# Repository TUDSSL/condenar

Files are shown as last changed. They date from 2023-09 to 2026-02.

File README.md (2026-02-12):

# TURNER Games Console

This is the official public repository for the TURNER battery-free gaming console.

<p align="center">
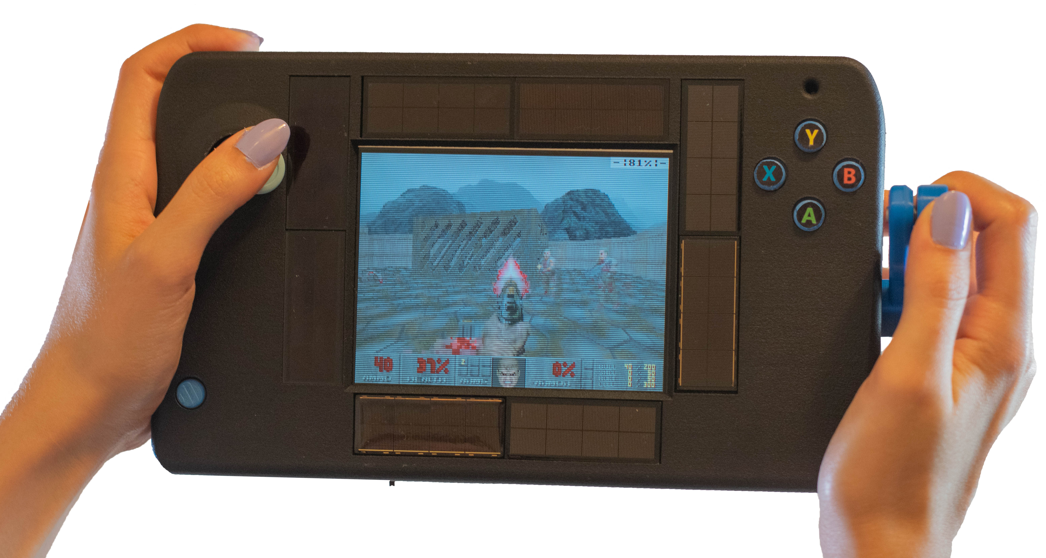
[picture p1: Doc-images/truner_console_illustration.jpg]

</p>

<p align="center">
  <sub><strong>Figure 1.</strong> The battery-free TURNER console in action. Turning the crank enables weapon firing in DOOM while simultaneously generating energy to charge TURNER’s energy-storage capacitor. The capacitor’s charging state is shown by a small indicator at the top-right of the LCD panel. TURNER integrates solar energy harvesting, follows the form factor of a modern handheld game console, and features the standard “ABXY” button configuration. The current implementation weighs 509 g; the casing measures 24 cm × 14 cm × 3 cm, and the crank measures 2 cm × 6.5 cm × 2 cm.</sub>
</p>

## System Design Rationale

Battery-free computer gaming offers a vision of sustainable interaction in which games run on hardware that does not require a battery, yet this approach introduces uncertainty due to frequent power failures. Rather than viewing these failures as limitations, this work examines how integrating energy harvesting with application design can encourage users to reimagine and work with such failures, thus shaping behaviour and supporting device use. We present TURNER, a state-of-the-art modular battery-free games console powered by a hand crank and solar cells, created as a research probe to study how energy harvesting mediates the relationship between power and interaction. 

In a subsequent mixed-methods study (N = 60), we explored the influence of energy harvesting on gameplay. Findings show significant variations in harvesting strategies, with interviews surfacing strategies for creating applications that respond to and build on the patterns of system power failure, the ergonomics of energy harvesting, and the value of embedding energy generation into play. Our work offers insights for interactive, sustainable battery-free computers.

## Repository Structure

- [/Hardware](https://github.com/tudssl/condenar/tree/master/Hardware): This folder contains the source files for the hardware used in this project.
- [/Software](https://github.com/tudssl/condenar/tree/master/Software): The folder contains the software used in the TURNER console (including console firmware, apps, and logging software).
- [/Data](https://github.com/tudssl/condenar/tree/master/Data): This folder contains the data and data analysis scripts used in the TURNER user study.
- [/Doc-images](https://github.com/TUDSSL/condenar/tree/master/Doc-images): This folder contains images of the TURNER console. 

## TURNER System Description

<p align="center">
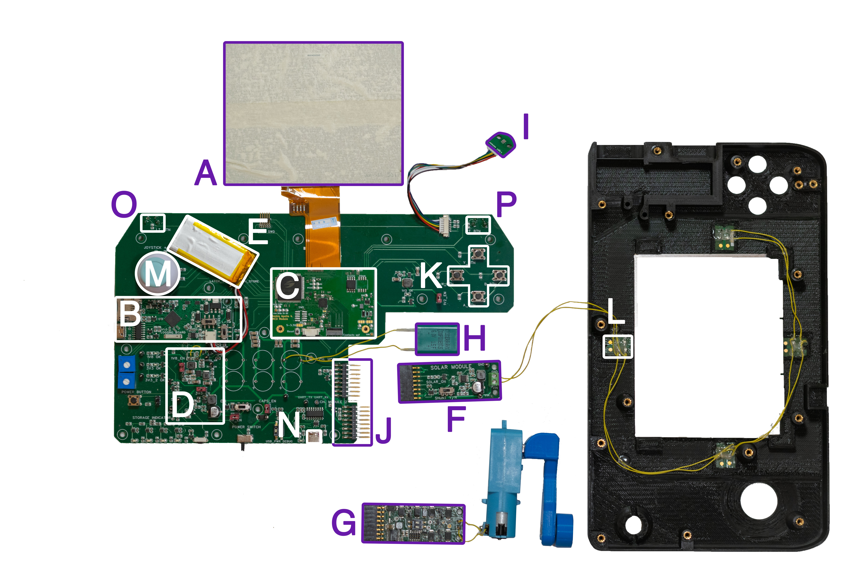
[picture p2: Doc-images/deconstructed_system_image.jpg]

</p>

<p align="center">
  <sub><strong>Figure 2.</strong> TURNER system implementation: (A) back of the COM50H5M81XLC transflective LCD screen; (B) logging module using an Espressif Systems ESP32 PICO Series microcontroller; (C) Central Processing Unit (CPU) module using an Ambiq Apollo4 MCU; (D) power management; (E) logging module battery; (F) solar module implemented around the Analog Devices LTC3129 Maximum Power Point Tracking (MPPT) buck-boost energy harvester; (G) crank module; (H) 6V 1.5F Kyocera AVX-SCM supercapacitor (SCMR22H155PSBB0); (I) ambient light sensor; (J) energy module connection points; (K) “ABXY” buttons; (L) solar panel connection on the front of the system casing. Eight ExCellLight EXL10-4V170 high-performance solar cells (50 mm × 20 mm each) are deployed; (M) joystick; (N) Universal Serial Bus (USB) port; (O) left trigger button; (P) right trigger button. The battery is used <em>only</em> to power the logging module and during the battery-powered console configuration experimental condition.</sub>
</p>

## TURNER User Study

The user study of TURNER employed a mixed-methods approach, combining console log data, questionnaire responses, and post-study interviews. The study was [pre-registed at Open Science Framework (OSF)](http://osf.io/7fp2w). 

### Quantitative Analysis

A range of statistical tests were used to assess the significance of effects in our log and questionnaire data. Parametric tests were applied when assumptions of normality, from Shapiro-Wilk, and homoscedasticity, from Levene's tests, were met. To analyse differences among more than two groups, we used Analysis of Variance (ANOVA) for between-subjects designs and repeated-measures ANOVA for within-subjects designs when parametric assumptions held, and Kruskal–Wallis or Friedman tests when non-parametric, respectively. Significant results were followed by post-hoc pairwise comparisons using Tukey’s HSD (parametric) or Dunn’s test with Bonferroni correction (non-parametric). For comparisons between two groups, we used independent samples t-tests or Mann-Whitney U tests, as appropriate. 

### Qualitative Analysis

We analysed post-study interviews using inductive thematic analysis, following the six-phase guidance proposed by [Braun and Clarke](https://www.tandfonline.com/doi/abs/10.1191/1478088706qp063oa). Coding was inductive, with initial descriptive and in vivo codes generated through repeated engagement with participants’ responses. Codes were iteratively refined and grouped into broader patterns through multiple rounds of analysis. 

## How to Cite This Work

The results of this project will be published in a peer-reviewed academic publication (from which all technical figures and most of the text in this file originate). Details of the publication are as follows.

* **Authors and the project team:** [James Scott Broadhead](https://scholar.google.com/citations?user=sMDFHlMAAAAJ), [Jasper de Winkel](https://jasperdewinkel.com), [Alejandro Cabrerizo Martinez de La Puente](https://www.linkedin.com/in/alejandro-cabrerizo-03780b136), [Himanshu Verma](https://vermahimanshu.com), [Przemysław Pawełczak](http://www.pawelczak.net)
* **Publication title:** _Connecting Power and Play: Investigating Interactive Energy Harvesting in Battery-Free Gaming_

<!--
* **Pulication venue:** [Proceedings of the 2026 CHI Conference on Human Factors in Computing Systems (CHI '26), April 13-17, 2026, Barcelona, Spain](https://dl.acm.org/)
* **Link to publication:** https://doi.org/10.1145/3772318.3790831 (Open Access)
* **Link to ACM CHI 2026 conference presentation video:** https://www.youtube.com/watch?
-->

<!--
To cite this publication please use the following BiBTeX entry.

```
@article{broadhead:chi:2026:turner,
  title = {Connecting Power and Play: Investigating Interactive Energy Harvesting in Battery-Free Gaming},
  author = {James Scott {Broadhead} and Jasper {de Winkel} and Alejandro Cabrerizo Martinez {de La Puente} and Himanshu {Verma} and Przemys{\l}aw {Pawe{\l}czak}},
  journal = {Proc. ACM Conference on Human Factors in Computing Systems (ACM CHI)},
  month =  apr # " 13--17",
  year = {2026},
  pages = {--},
  address = {Barcelona, Spain},
  publisher = {ACM}
}
```
-->

## Copyright

Copyright (C) 2026 TU Delft Embedded Systems Group/Sustainable Systems Laboratory.

MIT License or otherwise specified. See [license](https://github.com/TUDSSL/CONDENAR/blob/master/LICENSE) file for details.

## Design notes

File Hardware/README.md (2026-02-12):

# Files Relating to the Hardware Desing of the TURNER Console

This folder contains the hardware design files for the project, including component lists, enclosure designs, and printed circuit board layouts required to manufacture and assemble the system. Here you will find: 

- [BOM](https://github.com/TUDSSL/condenar/tree/master/Hardware/BOM): Bills of Materials listing all components required to assemble the hardware.

- [Enclosure](https://github.com/TUDSSL/condenar/tree/master/Hardware/Enclosure): Mechanical design files and documentation for the console casing.

- [PCBs](https://github.com/TUDSSL/condenar/tree/master/Hardware/PCBs): PCB design files for all hardware modules of the TURNER system.

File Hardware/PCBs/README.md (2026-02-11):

# PCBs

Each of the following folders has an associated PCB:

- [CPUModule](https://github.com/TUDSSL/condenar/tree/master/Hardware/PCBs/CPUModule): Module that hold the main processor, flash and display controller.
  
- [Logger](https://github.com/TUDSSL/condenar/tree/master/Hardware/PCBs/Logger): Optional module that can be used to record experiment data without affecting the system.
- [Mainboard](https://github.com/TUDSSL/condenar/tree/master/Hardware/PCBs/Mainboard): Main PCB, where all the different modules are connected.
- [PowerModules](https://github.com/TUDSSL/condenar/tree/master/Hardware/PCBs/PowerModules): The different power harvesting modules that generate power for the console. Up to two of them can be connected at the same time to the console.
- [Misc/Apo4devkit2COM50](https://github.com/TUDSSL/condenar/tree/master/Hardware/PCBs/Misc/Apo4devkit2COM50): Small shield PCB designed to test and measure the energy consumption of the SSD1963 IC
- [Misc/LightSensingModule](https://github.com/TUDSSL/condenar/tree/master/Hardware/PCBs/Misc/LightSensingModule): Small PCB that hosts a light sensor IC (OPT3001 or compatible from TI) to measure the ambient light.

Most PCB projects can be opened with Altium Designer (https://www.altium.com/altium-designer) directly. The CPUModule one uses KiCad (https://www.kicad.org/).

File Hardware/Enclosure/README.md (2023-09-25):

# 3D files
You can use any 3D CAD program of your choice to open and modify the .step files. Any .stl files can be also directly sent to the slicer for 3D printing.

## Buttons
ButtonNormal.step: A/B/X/Y buttons.

ButtonPower.step: The power button. It is special because it is sloped down and can't rotate.

ButtonTrigger.step: Trigger buttons. These buttons need to be carefully adapted to the 3D printer being used to print them since they require very strict tolerances.
	
## Enclosure
The enclosure is split into 2 pieces, Enclosure_Top.step, and Enclosure_Bottom.step
The top part is the one with the holes for the buttons, joystick, and screen.

## Enclosure_Bottom.step
This is the bottom part of the console enclosure.

## Crank
The crank is made out of 3 pieces: CrankBase, CrankHandle, and Crank Bottom.

The best way to print each of the parts of the crank (for maximum strength) can be seen in the picture below:
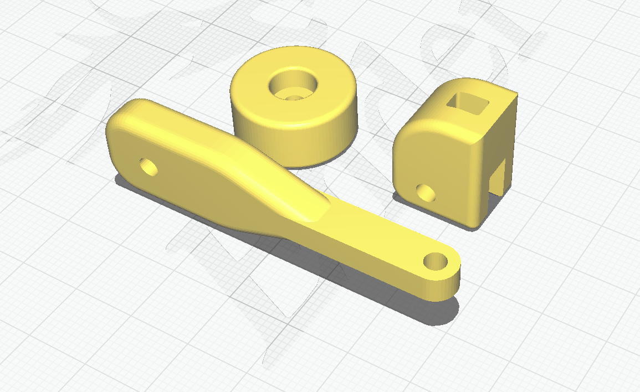
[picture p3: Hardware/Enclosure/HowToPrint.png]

Preliminary study cranks have been printed using Cura 5.3, using the default profiles, with 100% infill.

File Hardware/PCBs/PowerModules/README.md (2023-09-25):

# Power module PCBs

## Crank module
The crank module has gone through several iteration. The final one (the one used in the studies) is the "CrankModuleSMARTEST" one.

- CrankModuleV1: First version of the crank module. Not MCU/MPPT. Unidirectional.
- CrankModuleV2: Second version of the crank module. Efficiency improvements on low capacitor voltages. Not MCU/MPPT. Unidirectional.
- CrankModuleV2_SMART: CrankModuleV2 improved to add MPPT support. Unidirectional.
- CrankModuleV2_SMART: Builds upon CrankModuleV2_SMART to allow for custom MPPT algorithms, bidirectional cranking and feedback to the main console processor.

## Solar module

- SolarModule: Based on the CrankModuleV1 architecture, features a high-efficiency MPPT converter. Compatible with solar cells

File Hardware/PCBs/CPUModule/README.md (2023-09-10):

# CPU-Module

KiCad project of the CPU module, including the schematic, PCB layout and BOM.

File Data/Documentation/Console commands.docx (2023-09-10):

# Performing a hard reset (No checkpoints)

1. Turn the console fully off by sliding the power switch on the bottom to the left
2. Turn the main power back on by sliding that same switch to the right
3. Keep the following buttons pressed (both triggers and ‘A’):

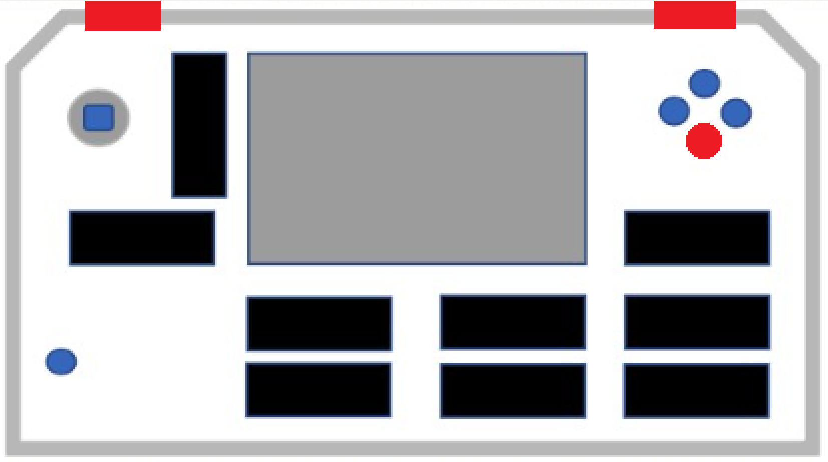
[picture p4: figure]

4. Press (no need to hold) the power button. After 1-2 seconds you can release the button combination from step 3.

# Resetting the settings to defaults

1. Turn the console fully off by sliding the power switch on the bottom to the left
2. Turn the main power back on by sliding that same switch to the right

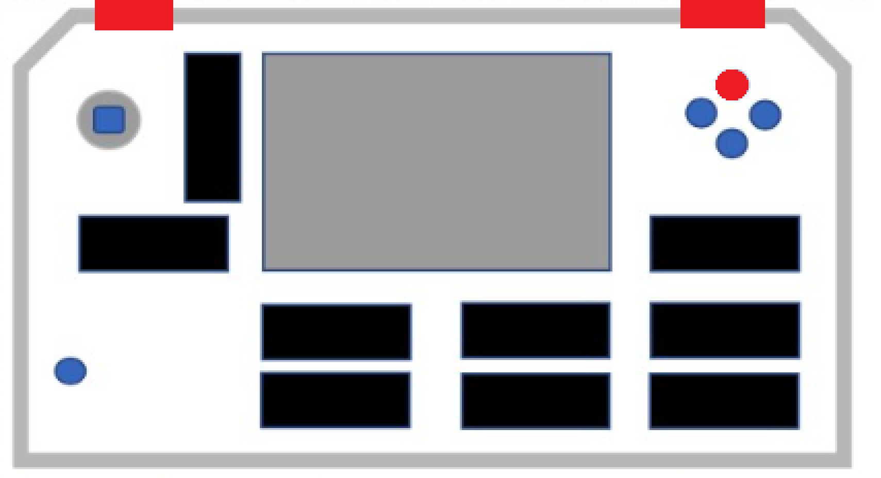
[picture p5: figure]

3. Keep the following buttons pressed (both triggers and ‘Y’):
4. Press (no need to hold) the power button. After 1-2 seconds you can release the button combination from step 3.

# Going back to the menu from any app

While pressing both triggers, push the joystick down (into the console). Keep pressing them until the console goes back to the menu. (It should take 1-2 seconds max)

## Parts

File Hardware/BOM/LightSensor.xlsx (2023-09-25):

No. | Quantity | Comment | Designator | Footprint | Value | Manufacturer Part | Manufacturer | Supplier Part | Supplier
1 | 1 | 100nF | C9 | C0603 |  | CC0603KRX7R9BB104 | YAGEO | C14663 | LCSC
2 | 1 | 532610671 | CN1 | CONN-SMD_6P-P1.25_53261-0671 |  | 532610671 | MOLEX | C99277 | LCSC
3 | 1 | OPT3001DNPR | U1 | USON6_L2.1-W2.1-P0.65-BL-EP |  | OPT3001DNPR | TI(德州仪器) | C90462 | LCSC

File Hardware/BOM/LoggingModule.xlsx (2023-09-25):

No. | Quantity | Comment | Designator | Footprint | Value | Manufacturer Part | Manufacturer | Supplier Part | Supplier
1 | 9 | 100nF | C1,C2,C3,C4,C5,C9,C10,C11,C53 | C0603 |  | CC0603KRX7R9BB104 | YAGEO | C14663 | LCSC
2 | 3 | 100nF | C12,C13,C14 | C0402_NEW |  | CL05B104KO5NNNC | SAMSUNG | C1525 | LCSC
3 | 7 | 10uF | C47,C48,C49,C50,C51,C52,C56 | C0402 |  | CL05A106MQ5NUNC | SAMSUNG | C15525 | LCSC
4 | 1 | 473521001 | CARD1 | SD-SMD_SD-47352-101 |  | 473521001 | MOLEX | C293569 | LCSC
5 | 2 | DF40C-50DP-0.4V(51) | CN1,CN4 | CONN-SMD_DF40C-50DP-0.4V |  | DF40C-50DP-0.4V(51) | HRS(广濑) | C424645 | LCSC
6 | 1 | X1502WR-03K-N0SN | CN3 | CONN-TH_3P-P1.50_X1502WR-03K-N0SN |  | X1502WR-03K-N0SN | XKB Connectivity(中国星坤) | C561535 | LCSC
7 | 3 | SS54 | D6,D7,D8 | SMA_L4.4-W2.8-LS5.4-R-RD |  | SS54 | MDD | C22452 | LCSC
8 | 1 | SLDA92-2R660G-S1TF | L5 | ANT-SMD_L9.00-W2.00 |  | SLDA92-2R660G-S1TF | Sunlord(顺络) | C361625 | LCSC
9 | 2 | KT-0603R | LED1,LED2 | LED0603-R-RD |  | KT-0603R | KENTO | C2286 | LCSC
10 | 2 | SS8050_C2150 | Q4,Q5 | SOT-23-3_L2.9-W1.3-P1.90-LS2.4-BR |  | SS8050 | CJ | C2150 | LCSC
11 | 7 | SI2302 | Q13,Q14,Q15,Q16,Q17,Q18,Q19 | SOT-23-3_L2.9-W1.3-P1.90-LS2.4-BR |  | SI2302 | YONGYUTAI(永裕泰) | C2891732 | LCSC
12 | 16 | 10K | R1,R3,R4,R5,R6,R7,R9,R10,R11,R47,R84,R85,R86,R87,R89,R90 | R0603 |  | 0603WAF1002T5E | UniOhm | C25804 | LCSC
13 | 2 | 5.1kΩ | R2,R8 | R0603 | 5.1kΩ | 0603WAF5101T5E | UNI-ROYAL(厚声) | C23186 | LCSC
14 | 2 | 1kΩ | R12,R91 | R0603 |  | 0603WAF1001T5E | UniOhm | C21190 | LCSC
15 | 2 | SS-3235S-L1 | SW1,SW16 | SW-SMD_SS-3235S-LX |  | SS-3235S-L1 | XKB Connectivity(中国星坤) | C500055 | LCSC
16 | 2 | TMUX1511RSVR | U1,U2 | UTQFN-16_L2.6-W1.8-P0.40-BL |  | TMUX1511RSVR | TI(德州仪器) | C2673275 | LCSC
17 | 2 |  | U3,U43 | SMD_PAD
18 | 1 | CH340B | U11 | SOIC-16_L9.9-W3.9-P1.27-LS6.0-BL |  | CH340B | WCH | C81010 | LCSC
19 | 1 | TP4056M | U40 | MSOP-8_L3.0-W3.0-P0.65-LS5.0-BL-EP |  | TP4056M | TOPPOWER(南京拓微) | C21417 | LCSC
20 | 1 | AMS1117-3.3 | U41 | SOT-223-3_L6.5-W3.4-P2.30-LS7.0-BR |  | AMS1117-3.3 | 美国AMS | C6186 | LCSC
21 | 1 | ESP32-PICO-V3 | U42 | LGA-48_L7.0-W7.0-P0.50-BL-EP5.0 |  | ESP32-PICO-V3 | ESPRESSIF(乐鑫) | C967022 | LCSC
22 | 1 | BMI055 | U44 | LGA-16_L4.5-W3.0-P0.50-BL |  | BMI055 | Bosch(博世) | C189620 | LCSC
23 | 1 | TYPE-C-31-M-12 | USBC1 | USB-C_SMD-TYPE-C-31-M-12 |  | TYPE-C-31-M-12 | 韩国韩荣 | C165948 | LCSC

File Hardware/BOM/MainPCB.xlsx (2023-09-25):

No. | Quantity | Comment | Designator | Footprint | Value | Manufacturer Part | Manufacturer | Supplier Part | Supplier
1 | 19 | 100nF | C1,C3,C7,C8,C10,C21,C25,C26,C27,C28,C29,C30,C31,C33,C38,C39,C40,C41,C58 | C0603 |  | CC0603KRX7R9BB104 | YAGEO | C14663 | LCSC
2 | 5 | 22uF | C2,C4,C5,C11,C12 | C1206 |  | CL31A226KPHNNNE | SAMSUNG | C5672 | LCSC
3 | 1 | 33pF | C6 | C0603 |  | CL10C330JB8NNNC | SAMSUNG | C1663 | LCSC
4 | 9 | 100uF | C13,C14,C16,C17,C18,C62,C63,C64,C65 | C1206 | 100uF | CL31A107MQHNNNE | SAMSUNG(三星) | C15008 | LCSC
5 | 9 | 10uF | C15,C42,C43,C44,C45,C46,C54,C55,C57 | C0805 | 10uF | CL21A106KAYNNNE | SAMSUNG(三星) | C15850 | LCSC
6 | 5 | 4.7uF | C22,C23,C24,C34,C36 | C0603 |  | CL10A475KO8NNNC | SAMSUNG | C19666 | LCSC
7 | 1 | 100pF | C60 | C0603 | 100pF | CL10C101JB8NNNC | SAMSUNG(三星) | C14858 | LCSC
8 | 1 | 1uF | C61 | C0603 | 1uF | CL10A105KB8NNNC | SAMSUNG(三星) | C15849 | LCSC
9 | 2 | DF40C-100DS-0.4V(51) | CN1,CN8 | CONN-SMD_DF40C-100DS-0.4V-51 |  | DF40C-100DS-0.4V(51) | HRS(广濑) | C597931 | LCSC
10 | 2 | DF40C-50DS-0.4V(51) | CN2,CN7 | CONN-SMD_DF40C-50DS-0.4V51 |  | DF40C-50DS-0.4V(51) | HRS(广濑) | C424646 | LCSC
11 | 1 | WAFER-MX1.25-6PWB | CN9 | CONN-SMD_6P-P1.25_XUNPU_WAFER-MX1.25-6PWB |  | WAFER-MX1.25-6PWB | XUNPU(讯普) | C3029363 | LCSC
12 | 1 | USBLC6-2SC6_C2827654 | D1 | SOT-23-6_L2.9-W1.6-P0.95-LS2.8-BL |  | USBLC6-2SC6 | TECH PUBLIC(台舟电子) | C2827654 | LCSC
13 | 2 | BAT54C,215 | D2,D3 | SOT-23-3_L2.9-W1.6-P1.90-LS2.8-BR |  | BAT54C,215 | Nexperia | C37704 | LCSC
14 | 1 | SS54 | D5 | SMA_L4.4-W2.8-LS5.4-R-RD |  | SS54 | MDD | C22452 | LCSC
15 | 6 |  | H1,H2,H3,H4,H5,H6 | HDR-TH_2P-P2.54-V-M-1
16 | 2 | TSM-108-02-F-SH | J1,J2 | TSM-108-YY-ZZZ-SH
17 | 2 | 2.2uH | L2,L4 | IND-SMD_L4.0-W4.0_SMNR4020 |  | SMNR4020-2.2UH | SXN | C135262 | LCSC
18 | 1 | 4.7uH | L6 | IND-SMD_L5.0-W5.0 | 4.7uH | SWPA5040S4R7NT | Sunlord(顺络) | C305174 | LCSC
19 | 1 | 470nH | L7 | IND-SMD_L5.0-W5.0 | 470nH | CR5020-R47N | ceaiya(柯爱亚) | C520328 | LCSC
20 | 6 | KT-0603R | LED1,LED4,LED5,LED6,LED11,LED12 | LED0603-R-RD |  | KT-0603R | KENTO | C2286 | LCSC
21 | 4 | 17-21SUYC/TR8 | LED7,LED8,LED9,LED10 | LED0805-RD |  | 17-21SUYC/TR8 | KENTO | C2296 | LCSC
22 | 2 | AO3401A | Q1,Q3 | SOT-23_L2.9-W1.3-P1.90-LS2.4-BR |  | AO3401A | AOS | C15127 | LCSC
23 | 10 | AO3400A | Q2,Q4,Q5,Q8,Q9,Q10,Q11,Q12,Q20,Q21 | SOT-23-3_L2.9-W1.3-P1.90-LS2.4-BR |  | AO3400A | HUASHUO(华朔) | C700953 | LCSC
24 | 3 | AO3400A_C700953 | Q6,Q7,Q13 | SOT-23-3_L2.9-W1.3-P1.90-LS2.4-BR |  | AO3400A | HUASHUO(华朔) | C700953 | LCSC
25 | 22 | 200kΩ | R3,R19,R23,R26,R27,R28,R31,R34,R38,R46,R48,R49,R50,R51,R52,R53,R60,R62,R65,R67,R70,R105 | R0603 |  | 0603WAF2003T5E | UniOhm | C25811 | LCSC
26 | 8 | 1MΩ | R4,R9,R35,R41,R69,R71,R73,R101 | R0603 |  | 0603WAF1004T5E | UniOhm | C22935 | LCSC
27 | 18 | 5.1MΩ | R5,R10,R17,R18,R29,R32,R33,R36,R37,R42,R43,R59,R81,R92,R93,R94,R95,R96 | R0603 |  | 0603WAF5104T5E | UniOhm | C13320 | LCSC
28 | 3 | 3MΩ | R8,R20,R66 | R0603 |  | 0603WAF3004T5E | UniOhm | C23156 | LCSC
29 | 2 | 2MΩ | R11,R106 | RES-ADJ-TH_3P-L9.5-W9.5-P2.54-BR-BS | 2MΩ | 3386P-1-205LF | BOURNS | C116289 | LCSC
30 | 1 | 470Ω | R12 | R0603 |  | 0603WAF4700T5E | UniOhm | C23179 | LCSC
31 | 6 | 1kΩ | R13,R21,R22,R44,R82,R83 | R0603 |  | 0603WAF1001T5E | UniOhm | C21190 | LCSC
32 | 3 | 5.1K | R14,R15,R16 | R0603 |  | 0603WAF5101T5E | UniOhm | C23186 | LCSC
33 | 3 | 470kΩ | R24,R25,R30 | R0603 |  | 0603WAF4703T5E | UniOhm | C23178 | LCSC
34 | 7 | 20kΩ | R39,R40,R45,R55,R56,R57,R58 | R0603 |  | 0603WAF2002T5E | UniOhm | C4184 | LCSC
35 | 4 | 10kΩ | R68,R74,R75,R76 | R0603 |  | 0603WAF1002T5E | UniOhm | C25804 | LCSC
36 | 1 | 200mΩ | R88 | R1206 | 200mΩ | PT1206FR-7W0R2L | YAGEO(国巨) | C309533 | LCSC
37 | 2 | 100kΩ | R107,R108 | R0603 | 100kΩ | 0603WAF1003T5E | UNI-ROYAL(厚声) | C25803 | LCSC
38 | 5 | TS665CJ | SW1,SW4,SW5,SW6,SW7 | SW-TH_4P-L6.0-W6.0-P4.50-LS6.5 |  | TS665CJ | SHOU HAN | C393938 | LCSC
39 | 1 | SK-12D02-VG5 | SW2 | SW-TH_SK-12D02-VG5 |  | SK-12D02-VG5 | Rectangular Connectors - Contacts | C136722 | LCSC
40 | 2 | TS-1093C-A9B3-D1 | SW8,SW9 | SW-TH_TS-1093C-A9B3-D1 |  | TS-1093C-A9B3-D1 | Yuandi | C493051 | LCSC
41 | 1 | THB001P | SW11 | SW-TH_THB001P |  | THB001P | C&K | C2685355 | LCSC
42 | 1 | K2-1112SW-A4SW-04 | SW12 | KEY-TH_K2-1112SW-AXXW-XX |  | K2-1112SW-A4SW-04 | Korean Hroparts Elec | C223811 | LCSC
43 | 1 | K3-2235D-F1 | SW13 | SW-TH_K3-2235D-F1 |  | K3-2235D-F1 | 韩国韩荣 | C189615 | LCSC
44 | 2 | DSIC01LSGET | SW14,SW15 | SW-SMD_DSIC01LSGET |  | DSIC01LSGET | YE | C54948 | LCSC
45 | 6 |  | U1,U12,U13,U15,U16,U46 | KR5R5H224R
46 | 13 | 5001 | U2,U5,U14,U28,U29,U30,U31,U32,U33,U34,U35,U37,U38 | TEST-TH_BD2.54-P1.39 |  | 5001 | Keystone | C238122 | LCSC
47 | 1 | TPS62400DRCR_C138724 | U3 | VSON-10_L3.0-W3.0-P0.50-TL-EP |  | TPS62400DRCR | TI | C138724 | LCSC
48 | 4 | TLV3691IDCKR | U7,U8,U9,U10 | SC-70-5_L2.1-W1.3-P0.65-LS2.1-BR |  | TLV3691IDCKR | TI(德州仪器) | C180352 | LCSC
49 | 1 | CH340B | U24 | SOIC-16_L9.9-W3.9-P1.27-LS6.0-BL |  | CH340B | WCH | C81010 | LCSC
50 | 1 | TPS2051BDBVR | U27 | SOT-23-5_L3.0-W1.7-P0.95-LS2.8-BR |  | TPS2051BDBVR | TI | C24593 | LCSC
51 | 1 | INA180A3IDBVR | U39 | SOT-23-5_L3.0-W1.7-P0.95-LS2.8-BR |  | INA180A3IDBVR | TI(德州仪器) | C122882 | LCSC
52 | 1 | TXS0102DCUR | U43 | US-8_L2.4-W2.1-P0.50-LS3.2-BR |  | TXS0102DCUR | TI(德州仪器) | C53434 | LCSC
53 | 1 | LTC3526LEDC#TRPBF | U44 | DFN-6_L2.0-W2.0-P0.50-BL-EP |  | LTC3526LEDC#TRPBF | ADI(亚德诺)/LINEAR | C684883 | LCSC
54 | 1 | SN74AHCT1G08DBVR | U48 | SOT-23-5_L3.0-W1.7-P0.95-LS2.8-BR |  | SN74AHCT1G08DBVR | TI(德州仪器) | C113521 | LCSC
55 | 1 | TPS62821DLCT | U51 | VSON-8_L2.0-W1.5-P0.50-BL |  | TPS62821DLCT | TI(德州仪器) | C2072013 | LCSC
56 | 1 |  | U54 | HDRRA10W40P127_2X5_635X100X340
57 | 1 | MIC841HYC5-TR | U55 | SC-70-5_L2.1-W1.3-P0.65-LS2.1-BL |  | MIC841HYC5-TR | MICROCHIP(美国微芯) | C511290 | LCSC
58 | 1 | TC7W74FU,LF | U56 | TSSOP-8_L3.0-W3.0-P0.65-LS4.9-BR |  | TC7W74FU,LF | TOSHIBA(东芝) | C128631 | LCSC
59 | 1 | TMUX1511RSVR | U57 | UTQFN-16_L2.6-W1.8-P0.40-BL |  | TMUX1511RSVR | TI(德州仪器) | C2673275 | LCSC
60 | 1 | 105450-0101 | USBC1 | USB-C-SMD_TYPE-C-USB-18 |  | 105450-0101 | MOLEX | C134092 | LCSC

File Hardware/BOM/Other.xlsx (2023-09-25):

Digikey
Description | Manufacturer name | Amount 1 console | Distributor part # | Link
Crank | Motor with gearbox, normal | 1 | 1528-2589-ND | https://www.digikey.nl/en/products/detail/adafruit-industries-llc/3777/8687221
Crank | Motor with gearbox, all metal, 2x gear ratio | 1 | 1528-2608-ND | https://www.digikey.nl/en/products/detail/adafruit-industries-llc/3802/9342523
Solar buck | LTC3129EMSE#PBF | 1 | 505-LTC3129EMSE#PBF-ND | https://www.digikey.nl/en/products/detail/analog-devices-inc/LTC3129EMSE-PBF/3913088
Header | SMH-108-02-G-S | 2 | SMH-108-02-G-S-ND | https://www.digikey.nl/en/products/detail/samtec-inc/SMH-108-02-G-S/10218741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
Header | TSM-108-02-L-SH | 2 | SAM15906-ND | https://www.digikey.nl/en/products/detail/samtec-inc/TSM-108-02-L-SH/7639234
Capacitor | KR-5R5H474-R | 3 | 283-2821-ND | https://www.digikey.nl/en/products/detail/eaton-electronics-division/KR-5R5H474-R/1556249
Button | TS11-674-105-BK-100-RA-D | 2 | 2223-TS11-674-105-BK-100-RA-D-ND | https://www.digikey.nl/en/products/detail/cui-devices/TS11-674-105-BK-100-RA-D/16562799
Button | TS11-674-43-BK-160-RA-D | 2 | TS11-674-43-BK-160-RA-D | https://www.digikey.nl/en/products/detail/cui-devices/TS11-674-43-BK-160-RA-D/16562767
Button | TS11-674-43-BK-100-RA-D | 2 | TS11-674-43-BK-100-RA-D | https://www.digikey.nl/en/products/detail/cui-devices/TS11-674-43-BK-100-RA-D/16562839
MPPC | LTC3105EDD#PBF | 1 | 505-LTC3105EDD#PBF-ND | https://www.digikey.nl/en/products/detail/analog-devices-inc/LTC3105EDD-PBF/2601179
SMART Crank MCU | NHS3152/A1Z | 1 | 568-13399-1-ND | https://www.digikey.nl/en/products/detail/nxp-usa-inc/NHS3152-A1Z/7227839
SWD connector | M50-3900542 | 1 | 952-1395-ND | https://www.digikey.nl/en/products/detail/harwin-inc/M50-3900542/2264376?s=N4IgTCBcDaILIFYAMBaAzATiUhAWCAugL5A
Light sensor connector | 532610671 | 2 | WM7624CT-ND | https://www.digikey.com/en/products/detail/molex/0532610671/699098?s=N4IgTCBcDaIAwFYDMYBsBGOqDs6QF0BfIA
LCSC
Description | Manufacturer name | Amount 1 console | Distributor part # | Link
LCD driver | SSD1963QL9 | 1 | C15216 | https://www.lcsc.com/product-detail/LCD-Drivers_Solomon-Systech-SSD1963QL9_C15216.html
Stud 11mm | HP-11M3*11 | 0 | C123698 | https://www.lcsc.com/product-detail/Stud-Copper-Column_HIWA-HP-11M3-11_C123698.html
Stud 8mm | HP-8M3*8 | 0 | C123699 | https://www.lcsc.com/product-detail/Stud-Copper-Column_HIWA-HP-8M3-8_C123699.html
Screw 15mm | PF3-15N | 0 | C194621 | https://www.lcsc.com/product-detail/Screws_HIWA-PF3-15N-M3-15_C194621.html

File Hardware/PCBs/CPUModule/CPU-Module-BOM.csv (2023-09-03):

Item | Qty | Reference(s) | Value | LibPart | Footprint | Datasheet | MPN
1 | 2 | C1, C3 | 6pF | Device:C | Capacitor_SMD:C_0402_1005Metric | ~ | CC0402BRNPO9BN6R0
2 | 6 | C2, C12, C13, C14, C15, C16 | 2.2 uF | Device:C | Capacitor_SMD:C_0201_0603Metric | ~ | GRM033R61A225KE47D
3 | 7 | C4, C18, C19, C23, C29, C32, C33 | 100nF | Device:C | Capacitor_SMD:C_0402_1005Metric | ~ | GRM155R71C104KA88J
4 | 2 | C5, C8 | 4pF DNP | Device:C | Capacitor_SMD:C_0402_1005Metric | ~ | CQ0402ARNPO9BN4R0
5 | 4 | C6, C7, C9, C10 | 1uF | Device:C | Capacitor_SMD:C_0201_0603Metric | ~ | GRM033C81A105ME05D
6 | 1 | C11 | 4.7nF | Device:C | Capacitor_SMD:C_0201_0603Metric | ~ | GRM033R61E472KA12D
7 | 9 | C17, C21, C22, C26, C27, C28, C30, C31, C34 | 1uF | Device:C | Capacitor_SMD:C_0402_1005Metric | ~ | CL05A105KP5NNNC
8 | 1 | C20 | 10uF | Device:C | Capacitor_SMD:C_0603_1608Metric | ~ | GRT188R61C106KE13D
9 | 1 | C24 | 2.2uF | Device:C | Capacitor_SMD:C_0603_1608Metric | ~ | GRM188R61H225KE11D
10 | 1 | C25 | 10uF | Device:C | Capacitor_SMD:C_0402_1005Metric | ~ | CL05A106MP8NUB8
11 | 1 | D1 | ESD | Device:D_Zener | Diode_SMD:D_SOD-523 | ~ | PESD5V0X1UB
12 | 1 | D2 | PMEG4050EP,115 | Device:D_Schottky_Filled | Diode_SMD:D_SOD-128 | ~ | PMEG4050EP,115
13 | 1 | D3 | BZX84J-C20,115 | Device:D_Schottky_Filled | Diode_SMD:D_SOD-323F | ~ | BZX84J-C20,115
14 | 1 | J1 | SWD_10 | jaspers_lib:SWD_10 | jaspers_footprints:ftsh-105-01-f-dv-k | http://infocenter.arm.com/help/topic/com.arm.doc.ddi0314h/DDI0314H_coresight_components_trm.pdf | ftsh-105-01-f-dv-k
15 | 1 | J3 | 52745-1097 | jaspers_lib:52745-1097 | jaspers_footprints:FPC_10_TOP | ~ | 52745-1097
16 | 1 | J8 | FH35C-25S-0.3SHW(50) | Connector_Generic_MountingPin:Conn_01x25_MountingPin | jaspers_footprints:FH35C-25S-0.3SHW_2Rows-27Pins-1MP_P0.60mm_Horizontal | ~ | FH35C-25S-0.3SHW(50)
17 | 2 | J10, J11 | DF40C-100DP-0-4V | jaspers_lib:DF40C-100DP-0-4V | jaspers_footprints:DF40C-100DP | ~ | DF40C-100DP-0-4V
18 | 1 | L1 | 2.2 uH | Device:L | Inductor_SMD:L_0805_2012Metric | ~ | DFE201210U-2R2M=P2
19 | 1 | L2 | LQH3NPH150MMEL | Device:L | jaspers_footprints:VLS6045EX | ~ | LQH3NPH150MMEL
20 | 3 | R1, R5, R14 | 100k | Device:R | Resistor_SMD:R_0402_1005Metric | ~ | ERJ-2RKF1003X
21 | 3 | R2, R3, R4 | 100 DNP | Device:R | Resistor_SMD:R_0201_0603Metric | ~ | CRCW0201100RFNED
22 | 1 | R6 | 0 | Device:R | Resistor_SMD:R_0402_1005Metric | ~ | ERJ-2GE0R00X
23 | 1 | R7 | DNP | Device:R | Resistor_SMD:R_0603_1608Metric | ~
24 | 4 | R8, R9, R10, R15 | 10M | Device:R | Resistor_SMD:R_0402_1005Metric | ~ | RC0402FR-0710ML
25 | 1 | R11 | 100k | Device:R | Resistor_SMD:R_0603_1608Metric | ~ | ERJ-3EKF1003V
26 | 1 | R12 | 100 | Device:R | Resistor_SMD:R_0603_1608Metric | ~ | CRCW0603100RFKEAHP
27 | 1 | R13 | ERJP06F10R0V | Device:R | Resistor_SMD:R_0805_2012Metric | ~ | ERJP06F10R0V
28 | 1 | SW1 | SW_Push | Switch:SW_Push | Button_Switch_SMD:SW_SPST_B3U-1000P | ~ | B3U-1000P
29 | 1 | U1 | Apollo_4 | jaspers_lib:Apollo_4 | jaspers_footprints:Apollo4-BGA-156_13x12_5.0x5.0mm |  | Apollo 4
30 | 2 | U2, U7 | SLG5NT1593V | jaspers_lib:SLG5NT1593V | jaspers_footprints:SLG5NT1593V | https://www.mouser.com/datasheet/2/665/silego_04052017_SLG5NT1593V-1105247.pdf | SLG5NT1593V
31 | 1 | U3 | SN74AUP3G34RSE | jaspers_lib:SN74AUP3G34RSE | jaspers_footprints:Texas_RSE_8_UQFN | https://www.ti.com/lit/ds/symlink/sn74aup3g34.pdf | SN74AUP3G34RSE
32 | 1 | U4 | LM3410XMF | jaspers_lib:LM3410XMF | Package_TO_SOT_SMD:SOT-23-5 | https://www.ti.com/lit/ds/symlink/lm3410.pdf | LM3410XMF
33 | 1 | U5 | MX25R6435FM2IH0 | jaspers_lib:MX25R6435FM2IH0 | Package_SO:SOP-8_5.28x5.23mm_P1.27mm | https://www.farnell.com/datasheets/2815329.pdf | MX25R6435FM2IH0
34 | 1 | U6 | MB85RS4MT | jaspers_lib:MB85RS4MT | Package_SO:SO-8_5.3x6.2mm_P1.27mm | https://www.fujitsu.com/global/documents/products/devices/semiconductor/fram/lineup/MB85RS4MT-DS501-00053-1v0-E.pdf | MB85RS4MT
35 | 1 | Y1 | 32.768Hz | Device:Crystal | Crystal:Crystal_SMD_MicroCrystal_CM9V-T1A-2Pin_1.6x1.0mm | http://www.txccrystal.com/images/pdf/9ht12.pdf | 9HT12-32.768KDZY
36 | 1 | Y2 | ABM12W-32.0000MHZ | jaspers_lib:ABM12W-32.0000MHZ | jaspers_footprints:Crystal_SMD_Abracon_ABM12B-4Pin_1.6x1.2mm | https://abracon.com/Resonators/ABM12W.pdf | ABM12W-32.0000MHZ-6-D1X-T3

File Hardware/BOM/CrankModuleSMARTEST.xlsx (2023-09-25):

No. | Quantity | Comment | Designator | Footprint | Value | Manufacturer Part | Manufacturer | Supplier Part | Supplier
1 | 5 | 100nF | C1,C8,C9,C10,C18 | C0603 |  | CC0603KRX7R9BB104 | YAGEO | C14663 | LCSC
2 | 2 | 22uF | C2,C3 | C0805 | 22uF | CL21A226MAQNNNE | SAMSUNG(三星) | C45783 | LCSC
3 | 1 | 10uF | C14 | C0603 | 10uF | CL10A106MA8NRNC | SAMSUNG(三星) | C96446 | LCSC
4 | 1 | 1uF | C17 | C0603 | 1uF | CL10A105KB8NNNC | SAMSUNG(三星) | C15849 | LCSC
5 | 1 | 100uF | C19 | C1210 | 100uF | CL32A107MQVNNNE | SAMSUNG(三星) | C49066 | LCSC
6 | 1 | 120uF | C20 | CAP-SMD_BD5.0-L5.3-W5.3-FD | 120uF | EEEFK1A121SR | PANASONIC(松下) | C336771 | LCSC
7 | 7 | STPS1L30U | D1,D2,D4,D5,D6,D7,D8 | SMB_L4.3-W3.6-LS5.4-RD |  | STPS1L30U | ST(意法半导体) | C222239 | LCSC
8 | 1 | SMAZ5V6-13-F | D9 | SMA_L4.3-W2.6-LS5.2-RD |  | SMAZ5V6-13-F | DIODES(美台) | C110526 | LCSC
9 | 1 | SMH-108-02-G-S-TR | J1 | SMH-108-02-XX-S-TR
10 | 4 | BSS806NEH6327 | Q1,Q2,Q14,Q15 | SOT-23_L2.9-W1.3-P1.90-LS2.4-BR |  | BSS806NEH6327 | Infineon(英飞凌) | C91714 | LCSC
11 | 4 | 20kΩ | R1,R17,R19,R45 | R0603 |  | 0603WAF2002T5E | UniOhm | C4184 | LCSC
12 | 17 | 100kΩ | R2,R3,R4,R7,R9,R11,R12,R13,R14,R15,R16,R18,R20,R21,R22,R23,R24 | R0603 | 100kΩ | 0603WAF1003T5E | UNI-ROYAL(厚声) | C25803 | LCSC
13 | 1 | 50mΩ | R92 | R1206 | 50mΩ | 1206W3F500MT5E | UNI-ROYAL(厚声) | C127691 | LCSC
14 | 1 | A6S-2102-PH | SW15 | SW-SMD_4P-L6.3-W6.1-P2.54-LS10.0-BL |  | A6S-2102-PH | OMRON(欧姆龙) | C3312217 | LCSC
15 | 5 | 5001 | U1,U2,U5,U15,U34 | TEST-TH_BD2.54-P1.39 |  | 5001 | Keystone | C238122 | LCSC
16 | 1 | KF350-3.5-2P | U13 | CONN-TH_P3.50_KF350-3.5-2P |  | KF350-3.5-2P | Cixi Kefa Elec | C474892 | LCSC
17 | 1 | INA180A3IDBVR | U39 | SOT-23-5_L3.0-W1.7-P0.95-LS2.8-BR |  | INA180A3IDBVR | TI(德州仪器) | C122882 | LCSC
18 | 1 | NHS3152/A1Z | U41 | QFN-24_L4.0-W4.0-P0.50-BL-EP2.6 |  | NHS3152/A1Z | NXP(恩智浦) | C2654832 | LCSC
19 | 1 | 20021121-00010T4LF | U42 | HDR-SMD_10P-P1.27-V-M-R2-C5-S1.27-LS5.5 |  | 20021121-00010T4LF | Amphenol | C598540 | LCSC
20 | 2 | FDN340P | U44,U45 | SOT-23-3_L2.9-W1.3-P0.95-LS2.4-BR |  | FDN340P | onsemi(安森美) | C3277832 | LCSC
21 | 1 | TPS3825-33DBVT | U47 | SOT-23-5_L3.0-W1.7-P0.95-LS2.8-BL |  | TPS3825-33DBVT | TI(德州仪器) | C131921 | LCSC
22 | 1 | LTC3106IFE#PBF | U48 | TSSOP-20_L6.5-W4.4-P0.65-LS6.4-BL-EP |  | LTC3106IFE#PBF | ADI(亚德诺)/LINEAR(凌特) | C684036 | LCSC
23 | 1 | MCP1700T-3302E/TT | U49 | SOT-23-3_L2.9-W1.6-P1.90-LS2.8-BR |  | MCP1700T-3302E/TT | MICROCHIP(美国微芯) | C39051 | LCSC
24 | 1 | MCP6041T-E/OT | U50 | SOT-23-5_L2.9-W1.6-P0.95-LS2.8-BR |  | MCP6041T-E/OT | MICROCHIP(美国微芯) | C623461 | LCSC
25 | 1 |  | U51 | LPS4018-223MRB

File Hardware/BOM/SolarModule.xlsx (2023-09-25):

No. | Quantity | Comment | Designator | Footprint | Value | Manufacturer Part | Manufacturer | Supplier Part | Supplier
1 | 1 | 100nF | C1 | C0603 |  | CC0603KRX7R9BB104 | YAGEO | C14663 | LCSC
2 | 5 | 4.7uF | C2,C3,C4,C6,C7 | C0603 |  | CL10A475KO8NNNC | SAMSUNG | C19666 | LCSC
3 | 1 | 220uF | C5 | CAP-SMD_BD6.3-L6.6-W6.6-LS7.2-R-RD |  | RVT1A221M0605 | HONOR | C3345 | LCSC
4 | 2 | 22nF | C14,C15 | C0603 | 22nF | CL10B223KB8NNNC | SAMSUNG(三星) | C21122 | LCSC
5 | 1 | 20pF | C16 | C0603 | 20pF | CL10C200JB8NNNC | SAMSUNG(三星) | C1648 | LCSC
6 | 1 | SMH-108-02-G-S-TR | J1 | SMH-108-02-XX-S-TR
7 | 1 | 4.7uH | L4 | IND-SMD_L5.0-W5.0 | 4.7uH | SWPA5040S4R7NT | Sunlord(顺络) | C305174 | LCSC
8 | 1 | KT-0603R | LED1 | LED0603-R-RD |  | KT-0603R | KENTO | C2286 | LCSC
9 | 1 | AO3400A | Q5 | SOT-23-3_L2.9-W1.6-P1.90-LS2.8-BR |  | AO3400A | AOS | C20917 | LCSC
10 | 2 | 1MΩ | R9,R14 | R0603 |  | 0603WAF1004T5E | UniOhm | C22935 | LCSC
11 | 1 | 5.1MΩ | R11 | R0603 |  | 0603WAF5104T5E | UniOhm | C13320 | LCSC
12 | 1 | 1kΩ | R12 | R0603 |  | 0603WAF1001T5E | UniOhm | C21190 | LCSC
13 | 1 | 3MΩ | R13 | R0603 |  | 0603WAF3004T5E | UniOhm | C23156 | LCSC
14 | 1 | 200kΩ | R40 | R0603 |  | 0603WAF2003T5E | UniOhm | C25811 | LCSC
15 | 1 | 22Ω | R88 | R0603 | 22Ω | 0603WAF220JT5E | UNI-ROYAL(厚声) | C23345 | LCSC
16 | 1 | K3-2235D-F1 | SW13 | SW-TH_K3-2235D-F1 |  | K3-2235D-F1 | 韩国韩荣 | C189615 | LCSC
17 | 2 | 5001 | U3,U15 | TEST-TH_BD2.54-P1.39 |  | 5001 | Keystone | C238122 | LCSC
18 | 1 | KF350-3.5-2P | U13 | CONN-TH_P3.50_KF350-3.5-2P |  | KF350-3.5-2P | Cixi Kefa Elec | C474892 | LCSC
19 | 1 | INA180A3IDBVR | U39 | SOT-23-5_L3.0-W1.7-P0.95-LS2.8-BR |  | INA180A3IDBVR | TI(德州仪器) | C122882 | LCSC
20 | 1 | LTC3129EMSE#PBF | U40 | MSOP-16_L4.0-W3.0-P0.50-LS4.9-BL-EP |  | LTC3129EMSE#PBF | ADI(亚德诺)/LINEAR | C684219 | LCSC

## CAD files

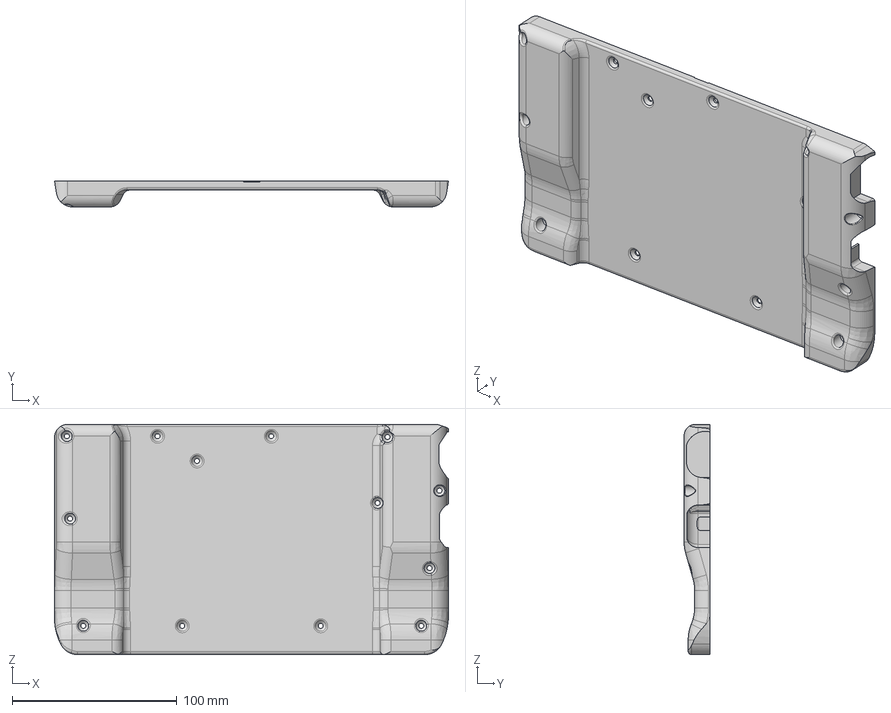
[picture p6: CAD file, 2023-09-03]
Hardware/Enclosure/Enclosure_Bottom.step
239.0 x 15.7 x 139.7 mm

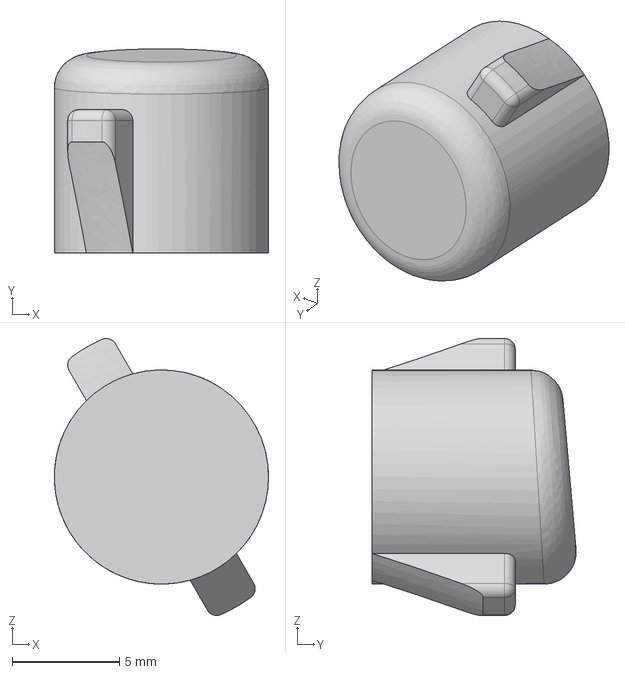
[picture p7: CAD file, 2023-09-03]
Hardware/Enclosure/ButtonPower.step
10.00 x 9.54 x 12.9 mm

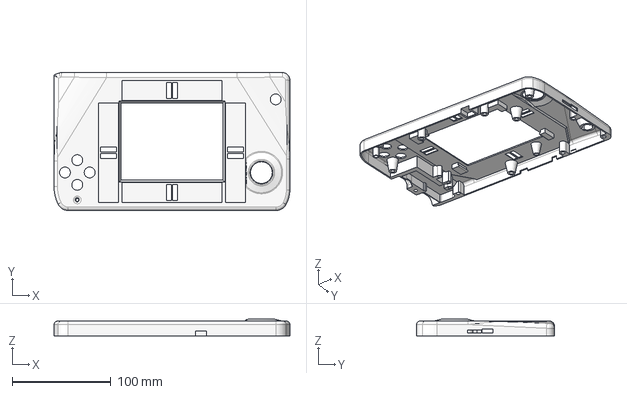
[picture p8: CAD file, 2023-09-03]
Hardware/Enclosure/EnclosureTop.step
239.0 x 139.7 x 17.0 mm

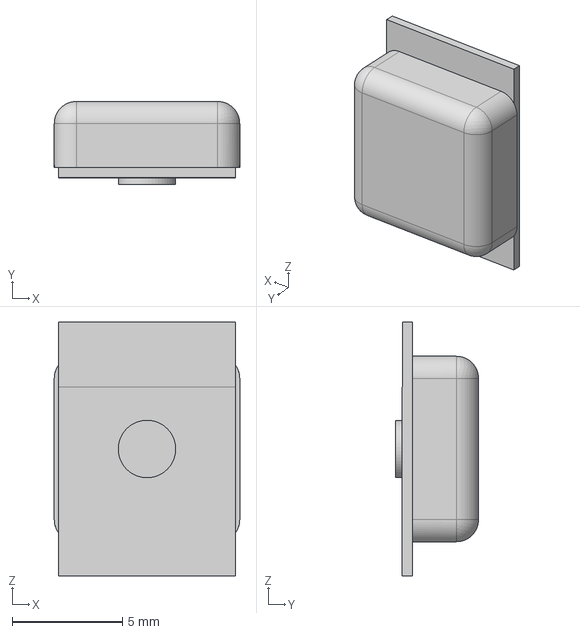
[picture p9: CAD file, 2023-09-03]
Hardware/Enclosure/ButtonTrigger.step
8.40 x 3.76 x 11.5 mm

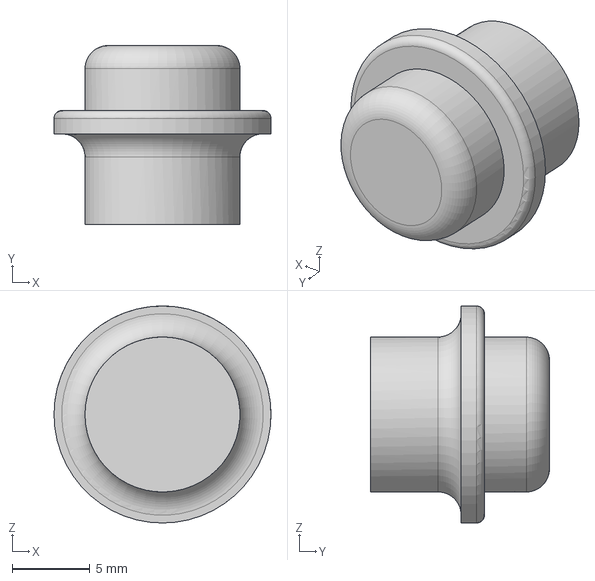
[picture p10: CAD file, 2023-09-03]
Hardware/Enclosure/ButtonNormal.step
14.0 x 11.6 x 14.0 mm

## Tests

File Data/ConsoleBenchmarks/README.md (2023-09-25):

# Console benchmarks

## Procedure and data collection
Power measurements were taken with a SDM3055 multimeter in series with the respective power rails.
Everything else was measured using the logging module of the console (through the logs it generates).

## Files in directory
- CheckpointingPerformance.xlsx: This file contains the theoretical calculations used to estimate the overhead that checkpointing creates. It is compared and graphed against FPS and the FPS limit set in the firmware.
- CrankTests.xlsx: This file contains multiple cranking output power tests carried out through the different iterations of the cranking module. Each experiment is on its own sheet, with the experiment setup described on top.
- SSD1963_PowerConsumption.xlsx: Contains power usage measurements taken directly from the power rails feeding the SSD1963 IC. Many different parameter combinations (PLL enabled, clock input frequency, output refresh frequency) are tested.

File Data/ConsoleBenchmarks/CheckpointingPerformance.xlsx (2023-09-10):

 |  | Heap % used
 |  | 25% | 50% | 75% | 100%
FPS | 5 | 0.375% | 0.5% | 0.625% | 0.75%
 | 10 | 0.75% | 1% | 1.25% | 1.5%
 | 15 | 1.125% | 1.5% | 1.875% | 2.25%
 | 20 | 1.5% | 2% | 2.5% | 3%
 | 25 | 1.875% | 2.5% | 3.125% | 3.75%
 | 30 | 2.25% | 3% | 3.75% | 4.5%
 | 35 | 2.625% | 3.5% | 4.375% | 5.25%
 | 40 | 3% | 4% | 5% | 6%
 | 45 | 3.375% | 4.5% | 5.625% | 6.75%
 | 50 | 3.75% | 5% | 6.25% | 7.5%
 | 55 | 4.125% | 5.5% | 6.875% | 8.25%
 | 60 | 4.5% | 6% | 7.5% | 9%
 |  | FPS Limit
 |  | 10.00 | 20.00 | 30.00 | 40.00 | 0 | Frame time
FPS | 5 | 0.375% | 0.5% | 0.625% | 0.75% |  | Frame time cap
 | 7.5 | 0.5625% | 0.75% | 0.9375% | 1.125% |  | Extra time = FrameTimeCap - Frametime
 | 10 | 0.75% | 1% | 1.25% | 1.5%
 | 12.5 | 0% | 1.25% | 1.5625% | 1.875%
 | 15 | 0% | 1.5% | 1.875% | 2.25%
 | 17.5 | 0% | 1.75% | 2.1875% | 2.625%
 | 20 | 0% | 2% | 2.5% | 3%
 | 22.5 | 0% | 0% | 2.8125% | 3.375%
 | 25 | 0% | 0% | 3.125% | 3.75%
 | 27.5 | 0% | 0% | 3.4375% | 4.125%
 | 30 | 0% | 0% | 3.75% | 4.5%
 | 32.5 | 0% | 0% | 0% | 4.875%
 | 35 | 0% | 0% | 0% | 5.25%
 | 37.5 | 0% | 0% | 0% | 5.625%
 | 40 | 0% | 0% | 0% | 6%
 | 42.5 | 0% | 0% | 0% | 0.125%
 | 45 | 0% | 0% | 0% | 0%
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

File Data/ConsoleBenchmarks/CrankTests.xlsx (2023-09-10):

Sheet: All metal
 |  |  | METAL, DUMB, 1RPS
 | 1.5 | F
 |  |  | V1 | V2
1 | 2 |  | 0 | 1 | 27 | 0 | 0.75 | 0.75 | 0.02777777778
 | 14 |  | 1 | 2 | 24 | 0.75 | 3 | 2.25 | 0.09375
 |  |  | 2 | 3 | 23 | 3 | 6.75 | 3.75 | 0.1630434783
 |  |  | 3 | 4 | 36 | 6.75 | 12 | 5.25 | 0.1458333333
 |  |  | 4 | 5 | 51 | 12 | 18.75 | 6.75 | 0.1323529412
2 | 3
 | 16
3 | 4
 | 21
4 | 5
 | 30

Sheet: All metal (2)
 |  |  | METAL, SMART 1RPS
 | 1.5 | F
 |  |  | V1 | V2
1 | 2 |  | 0 | 1 | 35 | 0 | 0.75 | 0.75 | 0.02142857143
 | 14 |  | 1 | 2 | 40 | 0.75 | 3 | 2.25 | 0.05625
 |  |  | 2 | 3 | 25 | 3 | 6.75 | 3.75 | 0.15
 |  |  | 3 | 4 | 42 | 6.75 | 12 | 5.25 | 0.125
 |  |  | 4 | 5 | 45 | 12 | 18.75 | 6.75 | 0.15
2 | 3
 | 16
3 | 4
 | 21
4 | 5
 | 30

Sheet: All metal (3)
 | 1.5 | F
 |  |  | V1 | V2
1 | 2 |  | 0 | 1 | 28 | 0 | 0.75 | 0.75 | 0.02678571429
 | 14 |  | 1 | 2 | 30 | 0.75 | 3 | 2.25 | 0.075
 |  |  | 2 | 3 | 30 | 3 | 6.75 | 3.75 | 0.125
 |  |  | 3 | 4 | 27 | 6.75 | 12 | 5.25 | 0.1944444444
 |  |  | 4 | 5 | 29 | 12 | 18.75 | 6.75 | 0.2327586207
2 | 3
 | 16
3 | 4
 | 21
4 | 5
 | 30
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

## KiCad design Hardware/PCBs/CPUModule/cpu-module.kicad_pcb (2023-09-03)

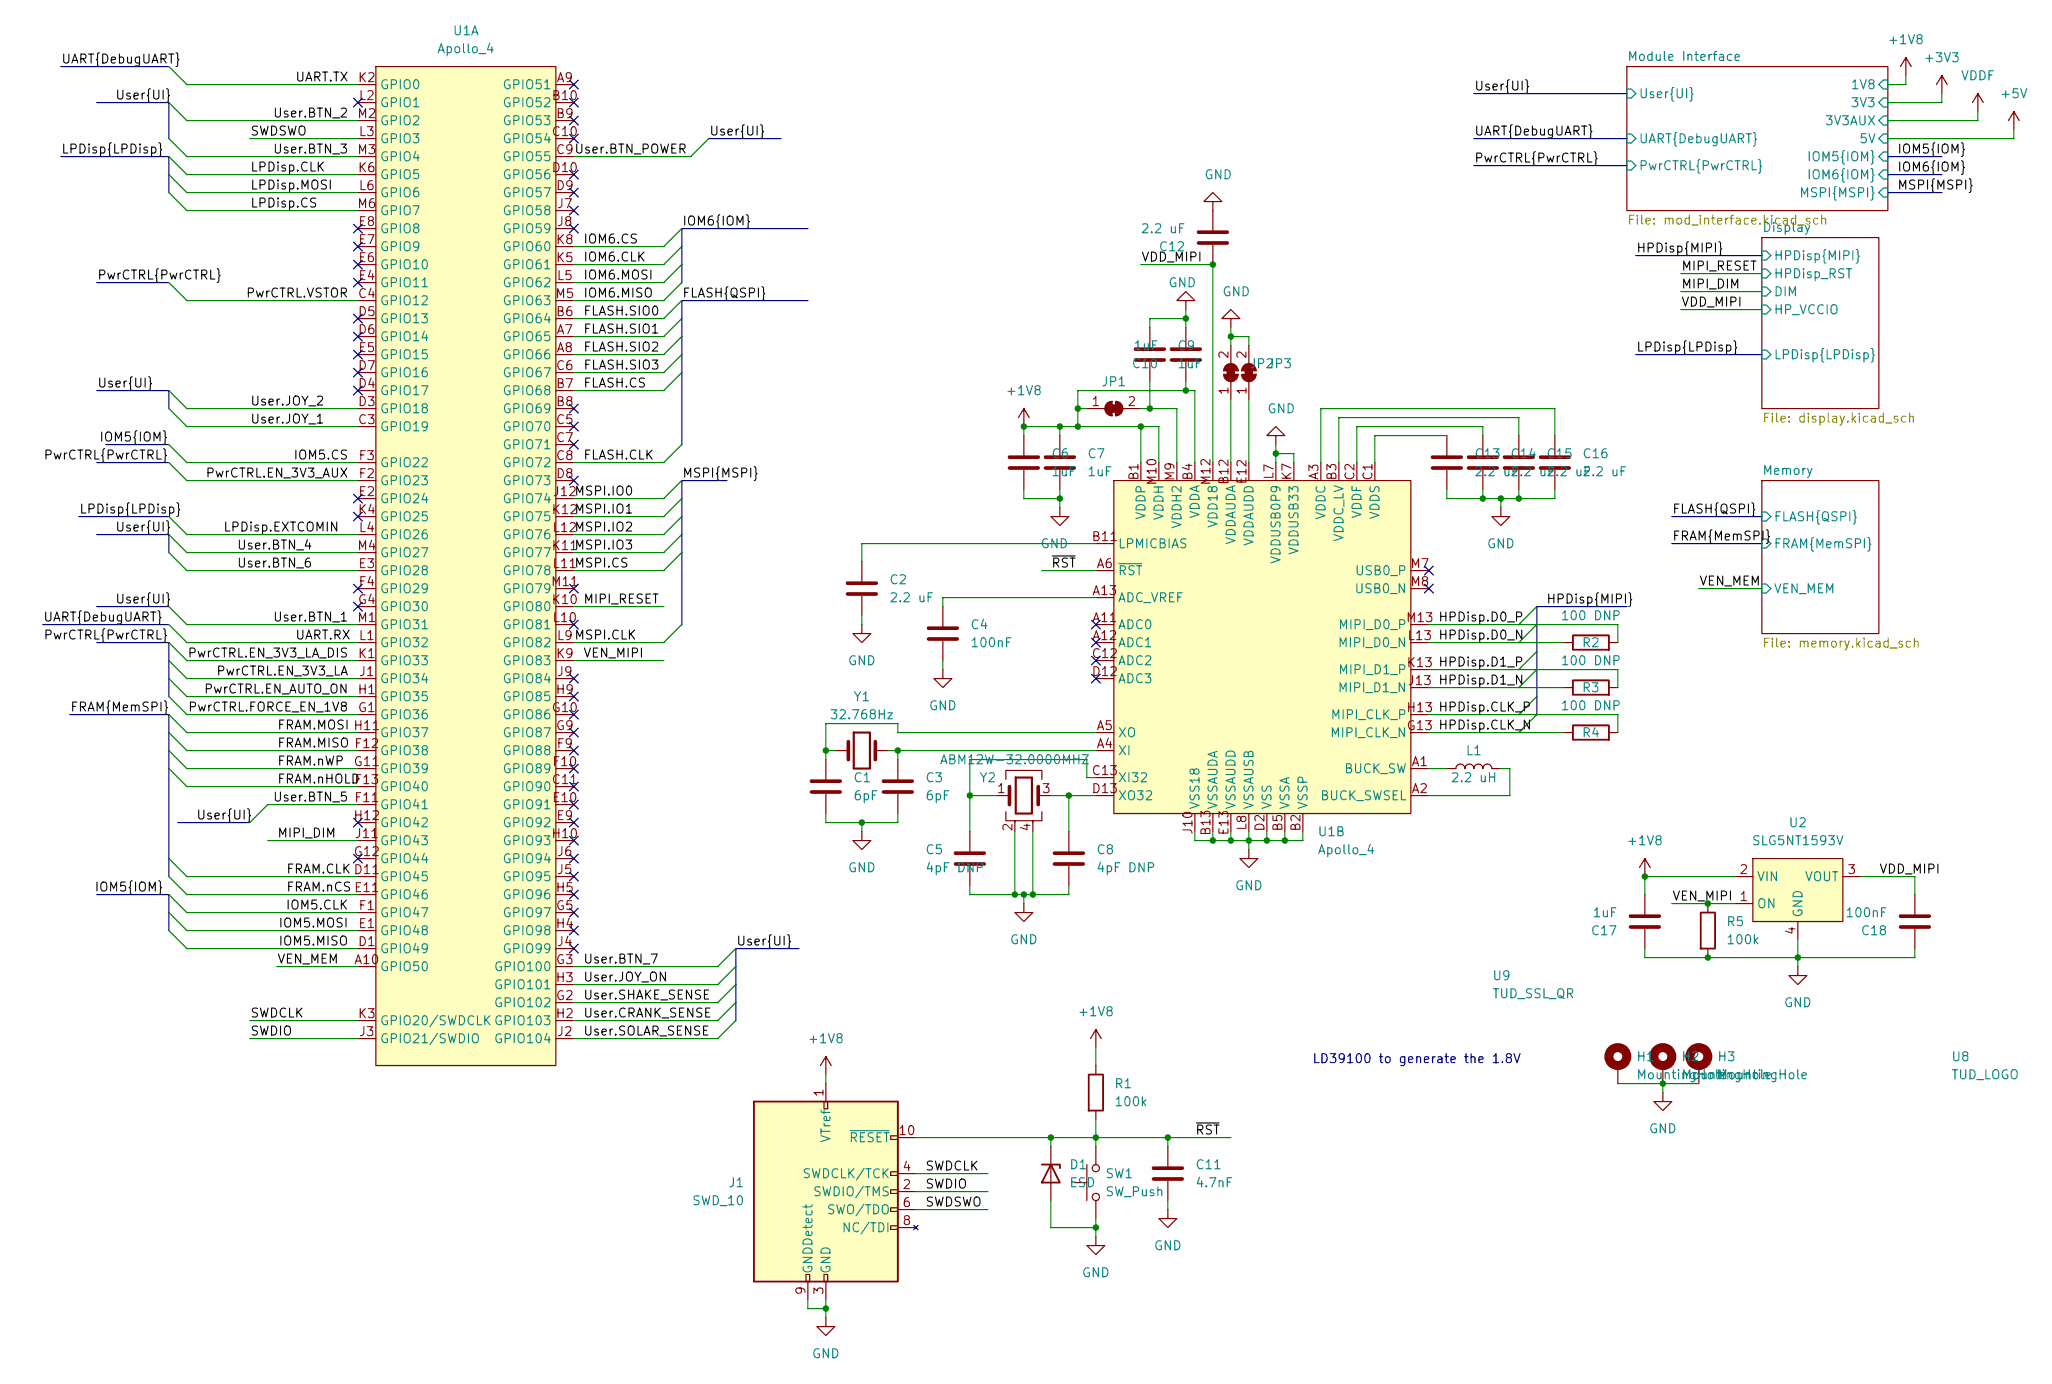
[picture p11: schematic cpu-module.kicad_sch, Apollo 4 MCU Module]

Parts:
C1, C3: 6pF; C_0402_1005Metric; MPN CC0402BRNPO9BN6R0
C2, C12, C13, C14, C15, C16: 2.2 uF; C_0201_0603Metric; MPN GRM033R61A225KE47D
C4, C18: 100nF; C_0402_1005Metric; MPN GRM155R71C104KA88J
C5, C8: 4pF DNP; C_0402_1005Metric; MPN CQ0402ARNPO9BN4R0
C6, C7, C9, C10: 1uF; C_0201_0603Metric; MPN GRM033C81A105ME05D
C11: 4.7nF; C_0201_0603Metric; MPN GRM033R61E472KA12D
C17: 1uF; C_0402_1005Metric; MPN CL05A105KP5NNNC
D1: ESD; D_SOD-523; MPN PESD5V0X1UB
H1, H2, H3: MountingHole; MountingHole_2.2mm_M2_Pad_Via
J1: SWD_10; ftsh-105-01-f-dv-k; MPN ftsh-105-01-f-dv-k
JP1, JP2, JP3: SolderJumper_2_Bridged; SolderJumper-small-nc
L1: 2.2 uH; L_0805_2012Metric; MPN DFE201210U-2R2M=P2
R1, R5: 100k; R_0402_1005Metric; MPN ERJ-2RKF1003X
R2, R3, R4: 100 DNP; R_0201_0603Metric; MPN CRCW0201100RFNED
SW1: SW_Push; SW_SPST_B3U-1000P; MPN B3U-1000P
U1: Apollo_4; Apollo4-BGA-156_13x12_5.0x5.0mm; MPN Apollo 4
U2: SLG5NT1593V; MPN SLG5NT1593V
U8: TUD_LOGO; DELFT_LOGO2
U9: TUD_SSL_QR; TUDSSL
Y1: 32.768Hz; Crystal_SMD_MicroCrystal_CM9V-T1A-2Pin_1.6x1.0mm; MPN 9HT12-32.768KDZY
Y2: ABM12W-32.0000MHZ; Crystal_SMD_Abracon_ABM12B-4Pin_1.6x1.2mm; MPN ABM12W-32.0000MHZ-6-D1X-T3

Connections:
+1V8: C6.1, C7.1, C10.1, C17.2, J1.1 (VTref), JP1.1 (A), R1.1, U1.B1 (VDDP), U1.B4 (VDDA), U1.M10 (VDDH), U2.2 (VIN); also elsewhere on the board
/FLASH.CLK: U1.C8 (GPIO72); also elsewhere on the board
/FLASH.CS: U1.B7 (GPIO68); also elsewhere on the board
/FLASH.SIO0: U1.B6 (GPIO64); also elsewhere on the board
/FLASH.SIO1: U1.A7 (GPIO65); also elsewhere on the board
/FLASH.SIO2: U1.A8 (GPIO66); also elsewhere on the board
/FLASH.SIO3: U1.C6 (GPIO67); also elsewhere on the board
/FRAM.CLK: U1.D11 (GPIO45); also elsewhere on the board
/FRAM.MISO: U1.F12 (GPIO38); also elsewhere on the board
/FRAM.MOSI: U1.H11 (GPIO37); also elsewhere on the board
/FRAM.nCS: U1.E11 (GPIO46); also elsewhere on the board
/FRAM.nHOLD: U1.F13 (GPIO40); also elsewhere on the board
/FRAM.nWP: U1.G11 (GPIO39); also elsewhere on the board
/HPDisp.CLK_N: R4.1, U1.G13 (MIPI_CLK_N); also elsewhere on the board
/HPDisp.CLK_P: R4.2, U1.H13 (MIPI_CLK_P); also elsewhere on the board
/HPDisp.D0_N: R2.1, U1.L13 (MIPI_D0_N); also elsewhere on the board
/HPDisp.D0_P: R2.2, U1.M13 (MIPI_D0_P); also elsewhere on the board
/HPDisp.D1_N: R3.1, U1.J13 (MIPI_D1_N); also elsewhere on the board
/HPDisp.D1_P: R3.2, U1.K13 (MIPI_D1_P); also elsewhere on the board
/IOM5.CLK: U1.F1 (GPIO47); also elsewhere on the board
/IOM5.CS: U1.F3 (GPIO22); also elsewhere on the board
/IOM5.MISO: U1.D1 (GPIO49); also elsewhere on the board
/IOM5.MOSI: U1.E1 (GPIO48); also elsewhere on the board
/IOM6.CLK: U1.K5 (GPIO61); also elsewhere on the board
/IOM6.CS: U1.K8 (GPIO60); also elsewhere on the board
/IOM6.MISO: U1.M5 (GPIO63); also elsewhere on the board
/IOM6.MOSI: U1.L5 (GPIO62); also elsewhere on the board
/LPDisp.CLK: U1.K6 (GPIO5); also elsewhere on the board
/LPDisp.CS: U1.M6 (GPIO7); also elsewhere on the board
/LPDisp.EXTCOMIN: U1.L4 (GPIO26); also elsewhere on the board
/LPDisp.MOSI: U1.L6 (GPIO6); also elsewhere on the board
/MIPI_DIM: U1.J11 (GPIO43); also elsewhere on the board
/MIPI_RESET: U1.K10 (GPIO80); also elsewhere on the board
/MSPI.CLK: U1.L9 (GPIO82); also elsewhere on the board
/MSPI.CS: U1.L11 (GPIO78); also elsewhere on the board
/MSPI.IO0: U1.J12 (GPIO74); also elsewhere on the board
/MSPI.IO1: U1.K12 (GPIO75); also elsewhere on the board
/MSPI.IO2: U1.L12 (GPIO76); also elsewhere on the board
/MSPI.IO3: U1.K11 (GPIO77); also elsewhere on the board
/PwrCTRL.EN_3V3_AUX: U1.F2 (GPIO23); also elsewhere on the board
/PwrCTRL.EN_3V3_LA: U1.J1 (GPIO34); also elsewhere on the board
/PwrCTRL.EN_3V3_LA_DIS: U1.K1 (GPIO33); also elsewhere on the board
/PwrCTRL.EN_AUTO_ON: U1.H1 (GPIO35); also elsewhere on the board
/PwrCTRL.FORCE_EN_1V8: U1.G1 (GPIO36); also elsewhere on the board
/PwrCTRL.VSTOR: U1.C4 (GPIO12); also elsewhere on the board
/SWDCLK: J1.4 (SWDCLK/TCK), U1.K3 (GPIO20/SWDCLK)
/SWDIO: J1.2 (SWDIO/TMS), U1.J3 (GPIO21/SWDIO)
/SWDSWO: J1.6 (SWO/TDO), U1.L3 (GPIO3)
/UART.RX: U1.L1 (GPIO32); also elsewhere on the board
/UART.TX: U1.K2 (GPIO0); also elsewhere on the board
/User.BTN_1: U1.M1 (GPIO31); also elsewhere on the board
/User.BTN_2: U1.M2 (GPIO2); also elsewhere on the board
/User.BTN_3: U1.M3 (GPIO4); also elsewhere on the board
/User.BTN_4: U1.M4 (GPIO27); also elsewhere on the board
/User.BTN_5: U1.F11 (GPIO41); also elsewhere on the board
/User.BTN_6: U1.E3 (GPIO28); also elsewhere on the board
/User.BTN_7: U1.G3 (GPIO100); also elsewhere on the board
/User.BTN_POWER: U1.C9 (GPIO55); also elsewhere on the board
/User.CRANK_SENSE: U1.H2 (GPIO103); also elsewhere on the board
/User.JOY_1: U1.C3 (GPIO19); also elsewhere on the board
/User.JOY_2: U1.D3 (GPIO18); also elsewhere on the board
/User.JOY_ON: U1.H3 (GPIO101); also elsewhere on the board
/User.SHAKE_SENSE: U1.G2 (GPIO102); also elsewhere on the board
/User.SOLAR_SENSE: U1.J2 (GPIO104); also elsewhere on the board
/VDD_MIPI: C12.1, C18.2, U1.M12 (VDD18), U2.3 (VOUT); also elsewhere on the board
/VEN_MEM: U1.A10 (GPIO50); also elsewhere on the board
/VEN_MIPI: R5.1, U1.K9 (GPIO83), U2.1 (ON)
/~RST: C11.1, D1.1 (K), J1.10 (~RESET), R1.2, SW1.2, U1.A6 (~RST)
GND: C1.2, C2.2, C3.2, C4.2, C5.2, C6.2, C7.2, C8.2, C9.2, C10.2, C11.2, C12.2, C13.2, C14.2, C15.2, C16.2, C17.1, C18.1, D1.2 (A), H1.1, H2.1, H3.1, J1.3 (GND), J1.5 (GND), J1.9 (GNDDetect), JP2.2 (B), JP3.2 (B), R5.2, SW1.1, U1.B2 (VSSP), U1.B5 (VSSA), U1.B13 (VSSAUDA), U1.D2 (VSS), U1.E13 (VSSAUDD), U1.J10 (VSS18), U1.K7 (VDDUSB33), U1.L7 (VDDUSB0P9), U1.L8 (VSSAUSB), U2.4 (GND), Y2.2, Y2.4; also elsewhere on the board
unnamed: C1.1, U1.A5 (XO), Y1.1
unnamed: C2.1, U1.B11 (LPMICBIAS)
unnamed: C3.1, U1.A4 (XI), Y1.2
unnamed: C4.1, U1.A13 (ADC_VREF)
unnamed: C5.1, U1.C13 (XI32), Y2.1
unnamed: C8.1, U1.D13 (XO32), Y2.3
unnamed: C9.1, JP1.2 (B), U1.M9 (VDDH2)
unnamed: C13.1, U1.C1 (VDDS)
unnamed: C14.1, U1.C2 (VDDF)
unnamed: C15.1, U1.B3 (VDDC_LV)
unnamed: C16.1, U1.A3 (VDDC)
unnamed: JP2.1 (A), U1.B12 (VDDAUDA)
unnamed: JP3.1 (A), U1.E12 (VDDAUDD)
unnamed: L1.1, U1.A1 (BUCK_SW)
unnamed: L1.2, U1.A2 (BUCK_SWSEL)

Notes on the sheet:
LD39100 to generate the 1.8V

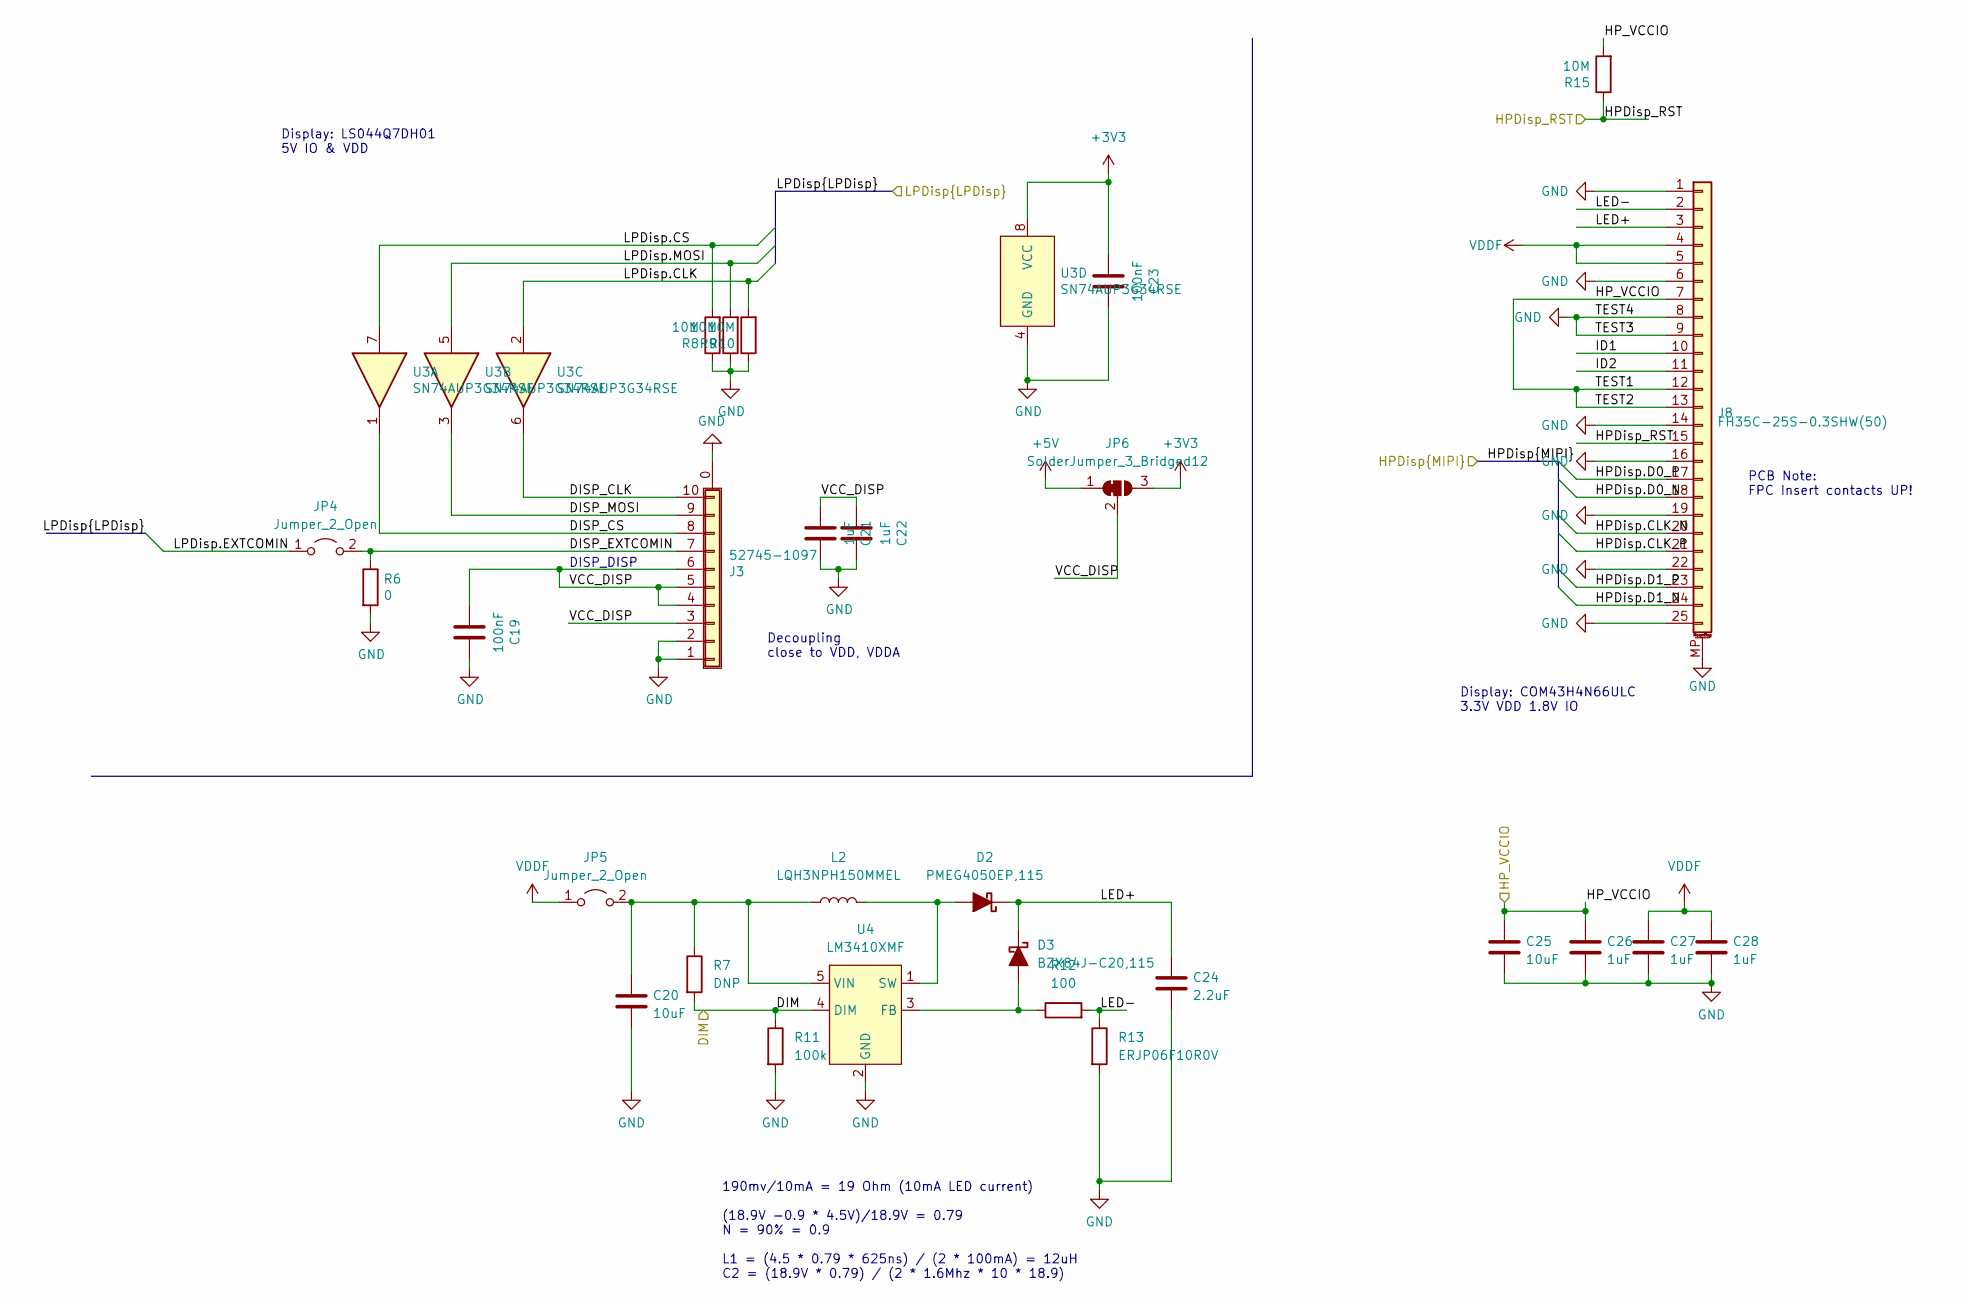
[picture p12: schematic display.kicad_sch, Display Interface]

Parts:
C19, C23: 100nF; C_0402_1005Metric; MPN GRM155R71C104KA88J
C20: 10uF; C_0603_1608Metric; MPN GRT188R61C106KE13D
C21, C22, C26, C27, C28: 1uF; C_0402_1005Metric; MPN CL05A105KP5NNNC
C24: 2.2uF; C_0603_1608Metric; MPN GRM188R61H225KE11D
C25: 10uF; C_0402_1005Metric; MPN CL05A106MP8NUB8
D2: PMEG4050EP,115; D_SOD-128; MPN PMEG4050EP,115
D3: BZX84J-C20,115; D_SOD-323F; MPN BZX84J-C20,115
J3: 52745-1097; FPC_10_TOP; MPN 52745-1097
J8: FH35C-25S-0.3SHW(50); FH35C-25S-0.3SHW_2Rows-27Pins-1MP_P0.60mm_Horizontal; MPN FH35C-25S-0.3SHW(50)
JP4, JP5: Jumper_2_Open; SolderJumper-small-no-150um
JP6: SolderJumper_3_Bridged12; SolderJumper-3_P1.3mm_Bridged12_RoundedPad1.0x1.5mm
L2: LQH3NPH150MMEL; VLS6045EX; MPN LQH3NPH150MMEL
R6: 0; R_0402_1005Metric; MPN ERJ-2GE0R00X
R7: DNP; R_0603_1608Metric
R8, R9, R10, R15: 10M; R_0402_1005Metric; MPN RC0402FR-0710ML
R11: 100k; R_0603_1608Metric; MPN ERJ-3EKF1003V
R12: 100; R_0603_1608Metric; MPN CRCW0603100RFKEAHP
R13: ERJP06F10R0V; R_0805_2012Metric; MPN ERJP06F10R0V
U3: SN74AUP3G34RSE; Texas_RSE_8_UQFN; MPN SN74AUP3G34RSE
U4: LM3410XMF; SOT-23-5; MPN LM3410XMF

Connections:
+3V3: C23.1, JP6.3 (B), U3.8 (VCC); also elsewhere on the board
+5V: JP6.1 (A); also elsewhere on the board
/Display/DISP_CLK: J3.10, U3.6
/Display/DISP_CS: J3.8, U3.1
/Display/DISP_EXTCOMIN: J3.7, JP4.2 (B), R6.1
/Display/DISP_MOSI: J3.9, U3.3
/Display/ID1: J8.10
/Display/ID2: J8.11
/Display/LED+: C24.1, D2.1 (K), D3.1 (K), J8.3
/Display/LED-: J8.2, R12.2, R13.1
/Display/VCC_DISP: C19.1, C21.1, C22.1, J3.3, J3.4, J3.5, J3.6, JP6.2 (C)
/HPDisp.CLK_N: J8.20; also elsewhere on the board
/HPDisp.CLK_P: J8.21; also elsewhere on the board
/HPDisp.D0_N: J8.18; also elsewhere on the board
/HPDisp.D0_P: J8.17; also elsewhere on the board
/HPDisp.D1_N: J8.24; also elsewhere on the board
/HPDisp.D1_P: J8.23; also elsewhere on the board
/LPDisp.CLK: R10.2, U3.2; also elsewhere on the board
/LPDisp.CS: R8.2, U3.7; also elsewhere on the board
/LPDisp.EXTCOMIN: JP4.1 (A); also elsewhere on the board
/LPDisp.MOSI: R9.2, U3.5; also elsewhere on the board
/MIPI_DIM: R7.2, R11.1, U4.4 (DIM); also elsewhere on the board
/MIPI_RESET: J8.15, R15.1; also elsewhere on the board
/VDD_MIPI: C25.1, C26.1, J8.7, J8.12, J8.13, R15.2; also elsewhere on the board
GND: C19.2, C20.2, C21.2, C22.2, C23.2, C24.2, C25.2, C26.2, C27.2, C28.2, J3.0 (Shield), J3.1, J3.2, J8.1, J8.6, J8.8, J8.9, J8.14, J8.16, J8.19, J8.22, J8.25, J8.MP (MountPin), R6.2, R8.1, R9.1, R10.1, R11.2, R13.2, U3.4 (GND), U4.2 (GND); also elsewhere on the board
unnamed: C20.1, JP5.2 (B), L2.1, R7.1, U4.5 (VIN)
unnamed: D2.2 (A), L2.2, U4.1 (SW)
unnamed: D3.2 (A), R12.1, U4.3 (FB)
VDDF: C27.1, C28.1, J8.4, J8.5, JP5.1 (A); also elsewhere on the board

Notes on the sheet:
190mv/10mA = 19 Ohm (10mA LED current) (18.9V -0.9 * 4.5V)/18.9V = 0.79 N = 90% = 0.9 L1 = (4.5 * 0.79 * 625ns) / (2 * 100mA) = 12uH C2 = (18.9V * 0.79) / (2 * 1.6Mhz * 10 * 18.9)
Display: COM43H4N66ULC 3.3V VDD 1.8V IO
Decoupling close to VDD, VDDA
DISP_DISP
PCB Note: FPC Insert contacts UP!
Display: LS044Q7DH01 5V IO & VDD

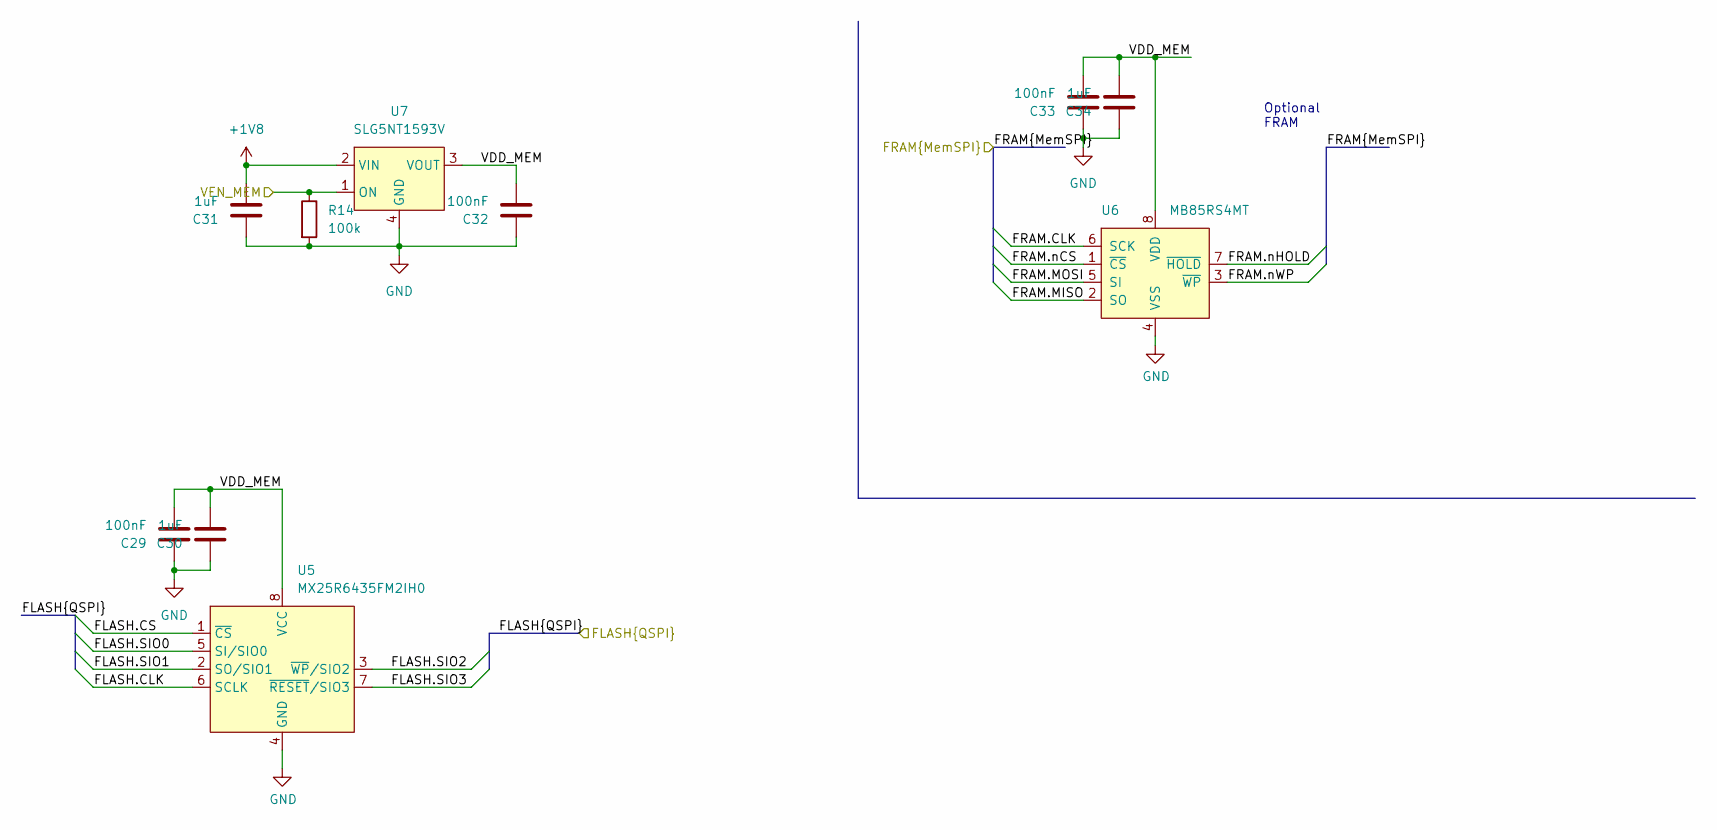
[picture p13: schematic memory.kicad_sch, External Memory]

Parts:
C29, C32, C33: 100nF; C_0402_1005Metric; MPN GRM155R71C104KA88J
C30, C31, C34: 1uF; C_0402_1005Metric; MPN CL05A105KP5NNNC
R14: 100k; R_0402_1005Metric; MPN ERJ-2RKF1003X
U5: MX25R6435FM2IH0; SOP-8_5.28x5.23mm_P1.27mm; MPN MX25R6435FM2IH0
U6: MB85RS4MT; SO-8_5.3x6.2mm_P1.27mm; MPN MB85RS4MT
U7: SLG5NT1593V; MPN SLG5NT1593V

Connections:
+1V8: C31.2, U7.2 (VIN); also elsewhere on the board
/FLASH.CLK: U5.6 (SCLK); also elsewhere on the board
/FLASH.CS: U5.1 (~CS); also elsewhere on the board
/FLASH.SIO0: U5.5 (SI/SIO0); also elsewhere on the board
/FLASH.SIO1: U5.2 (SO/SIO1); also elsewhere on the board
/FLASH.SIO2: U5.3 (~WP/SIO2); also elsewhere on the board
/FLASH.SIO3: U5.7 (~RESET/SIO3); also elsewhere on the board
/FRAM.CLK: U6.6 (SCK); also elsewhere on the board
/FRAM.MISO: U6.2 (SO); also elsewhere on the board
/FRAM.MOSI: U6.5 (SI); also elsewhere on the board
/FRAM.nCS: U6.1 (~CS); also elsewhere on the board
/FRAM.nHOLD: U6.7 (~HOLD); also elsewhere on the board
/FRAM.nWP: U6.3 (~WP); also elsewhere on the board
/Memory/VDD_MEM: C29.2, C30.2, C32.2, C33.2, C34.2, U5.8 (VCC), U6.8 (VDD), U7.3 (VOUT)
/VEN_MEM: R14.1, U7.1 (ON); also elsewhere on the board
GND: C29.1, C30.1, C31.1, C32.1, C33.1, C34.1, R14.2, U5.4 (GND), U6.4 (VSS), U7.4 (GND); also elsewhere on the board

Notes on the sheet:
Optional FRAM

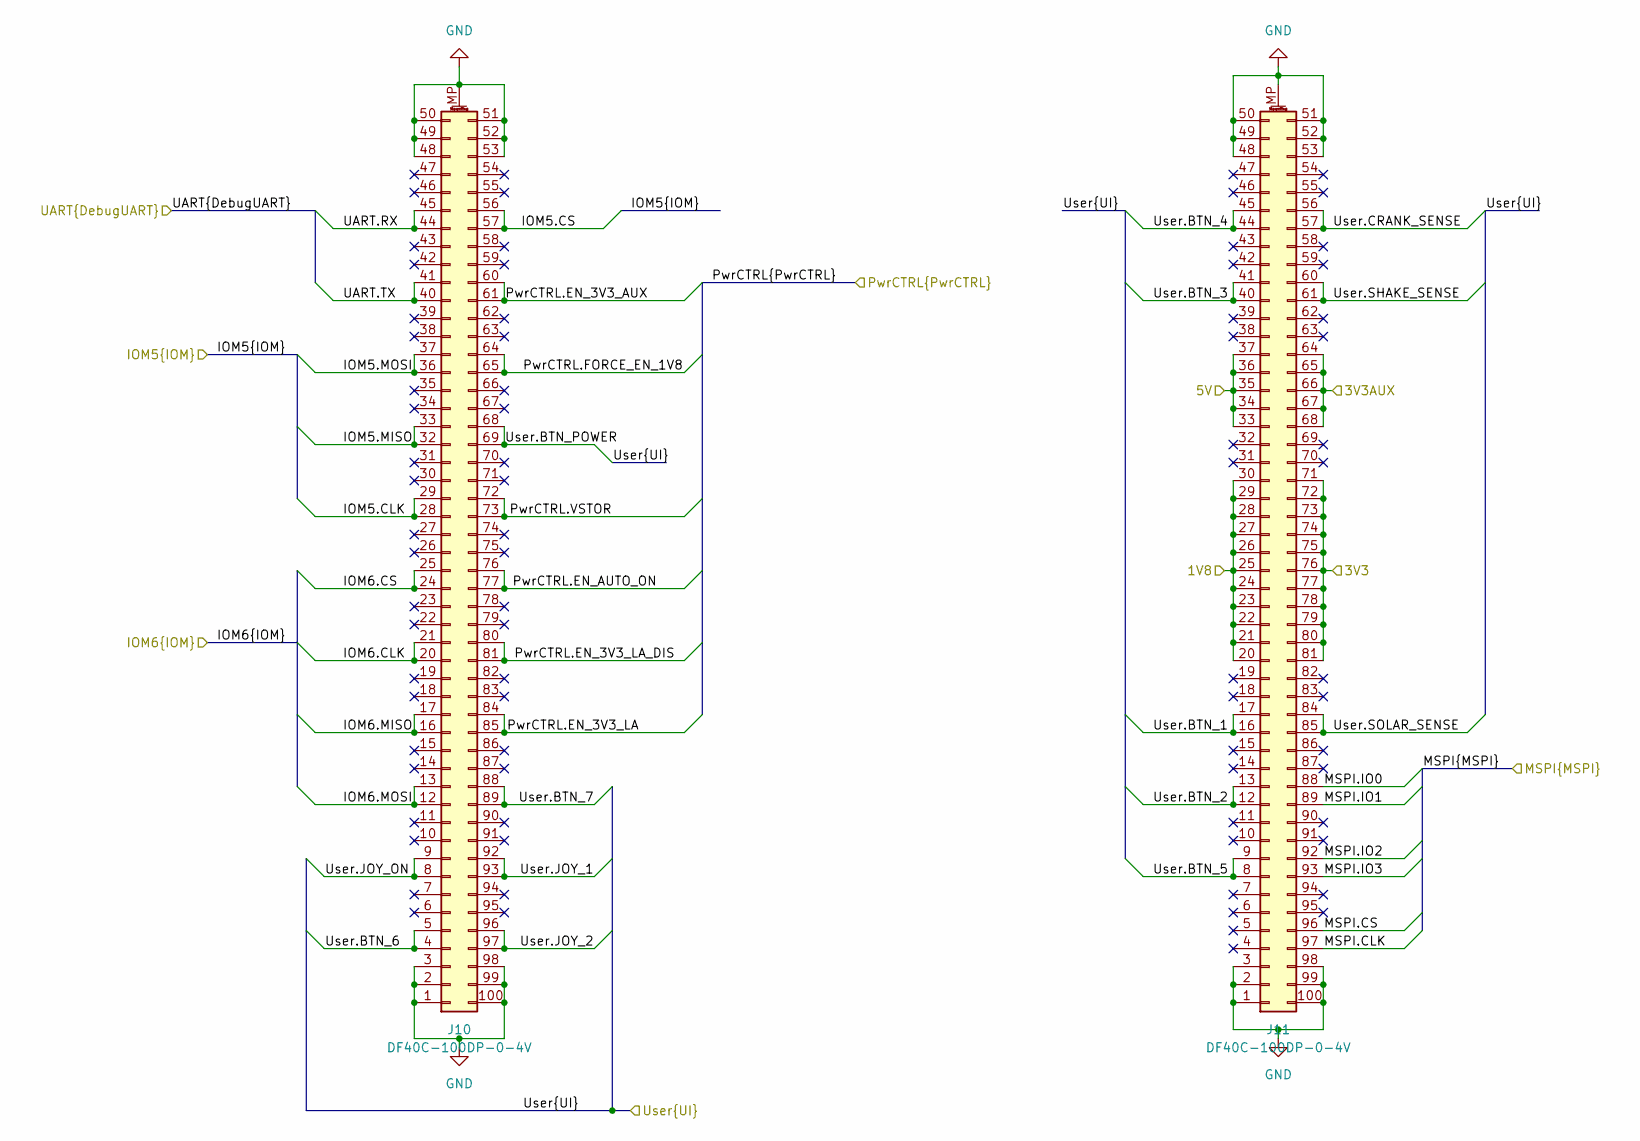
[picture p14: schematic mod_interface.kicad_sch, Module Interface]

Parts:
J10, J11: DF40C-100DP-0-4V; DF40C-100DP; MPN DF40C-100DP-0-4V

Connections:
+1V8: J11.20, J11.21, J11.22, J11.23, J11.24, J11.25, J11.26, J11.27, J11.28, J11.29, J11.30; also elsewhere on the board
+3V3: J11.71, J11.72, J11.73, J11.74, J11.75, J11.76, J11.77, J11.78, J11.79, J11.80, J11.81; also elsewhere on the board
+5V: J11.33, J11.34, J11.35, J11.36, J11.37; also elsewhere on the board
/IOM5.CLK: J10.28, J10.29; also elsewhere on the board
/IOM5.CS: J10.56, J10.57; also elsewhere on the board
/IOM5.MISO: J10.32, J10.33; also elsewhere on the board
/IOM5.MOSI: J10.36, J10.37; also elsewhere on the board
/IOM6.CLK: J10.20, J10.21; also elsewhere on the board
/IOM6.CS: J10.24, J10.25; also elsewhere on the board
/IOM6.MISO: J10.16, J10.17; also elsewhere on the board
/IOM6.MOSI: J10.12, J10.13; also elsewhere on the board
/MSPI.CLK: J11.97; also elsewhere on the board
/MSPI.CS: J11.96; also elsewhere on the board
/MSPI.IO0: J11.88; also elsewhere on the board
/MSPI.IO1: J11.89; also elsewhere on the board
/MSPI.IO2: J11.92; also elsewhere on the board
/MSPI.IO3: J11.93; also elsewhere on the board
/PwrCTRL.EN_3V3_AUX: J10.60, J10.61; also elsewhere on the board
/PwrCTRL.EN_3V3_LA: J10.84, J10.85; also elsewhere on the board
/PwrCTRL.EN_3V3_LA_DIS: J10.80, J10.81; also elsewhere on the board
/PwrCTRL.EN_AUTO_ON: J10.76, J10.77; also elsewhere on the board
/PwrCTRL.FORCE_EN_1V8: J10.64, J10.65; also elsewhere on the board
/PwrCTRL.VSTOR: J10.72, J10.73; also elsewhere on the board
/UART.RX: J10.44, J10.45; also elsewhere on the board
/UART.TX: J10.40, J10.41; also elsewhere on the board
/User.BTN_1: J11.16, J11.17; also elsewhere on the board
/User.BTN_2: J11.12, J11.13; also elsewhere on the board
/User.BTN_3: J11.40, J11.41; also elsewhere on the board
/User.BTN_4: J11.44, J11.45; also elsewhere on the board
/User.BTN_5: J11.8, J11.9; also elsewhere on the board
/User.BTN_6: J10.4, J10.5; also elsewhere on the board
/User.BTN_7: J10.88, J10.89; also elsewhere on the board
/User.BTN_POWER: J10.68, J10.69; also elsewhere on the board
/User.CRANK_SENSE: J11.56, J11.57; also elsewhere on the board
/User.JOY_1: J10.92, J10.93; also elsewhere on the board
/User.JOY_2: J10.96, J10.97; also elsewhere on the board
/User.JOY_ON: J10.8, J10.9; also elsewhere on the board
/User.SHAKE_SENSE: J11.60, J11.61; also elsewhere on the board
/User.SOLAR_SENSE: J11.84, J11.85; also elsewhere on the board
GND: J10.1, J10.2, J10.3, J10.48, J10.49, J10.50, J10.51, J10.52, J10.53, J10.98, J10.99, J10.100, J10.MP (MountPin), J11.1, J11.2, J11.3, J11.48, J11.49, J11.50, J11.51, J11.52, J11.53, J11.98, J11.99, J11.100, J11.MP (MountPin); also elsewhere on the board
VDDF: J11.64, J11.65, J11.66, J11.67, J11.68; also elsewhere on the board

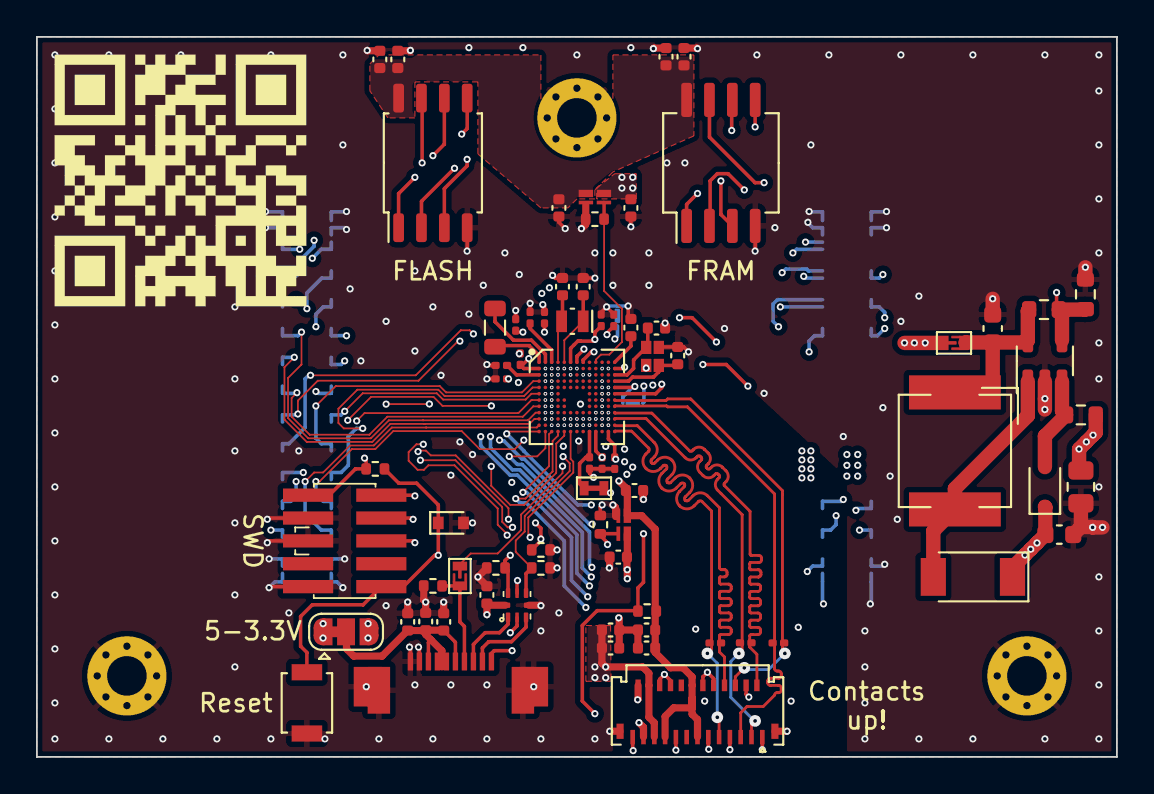
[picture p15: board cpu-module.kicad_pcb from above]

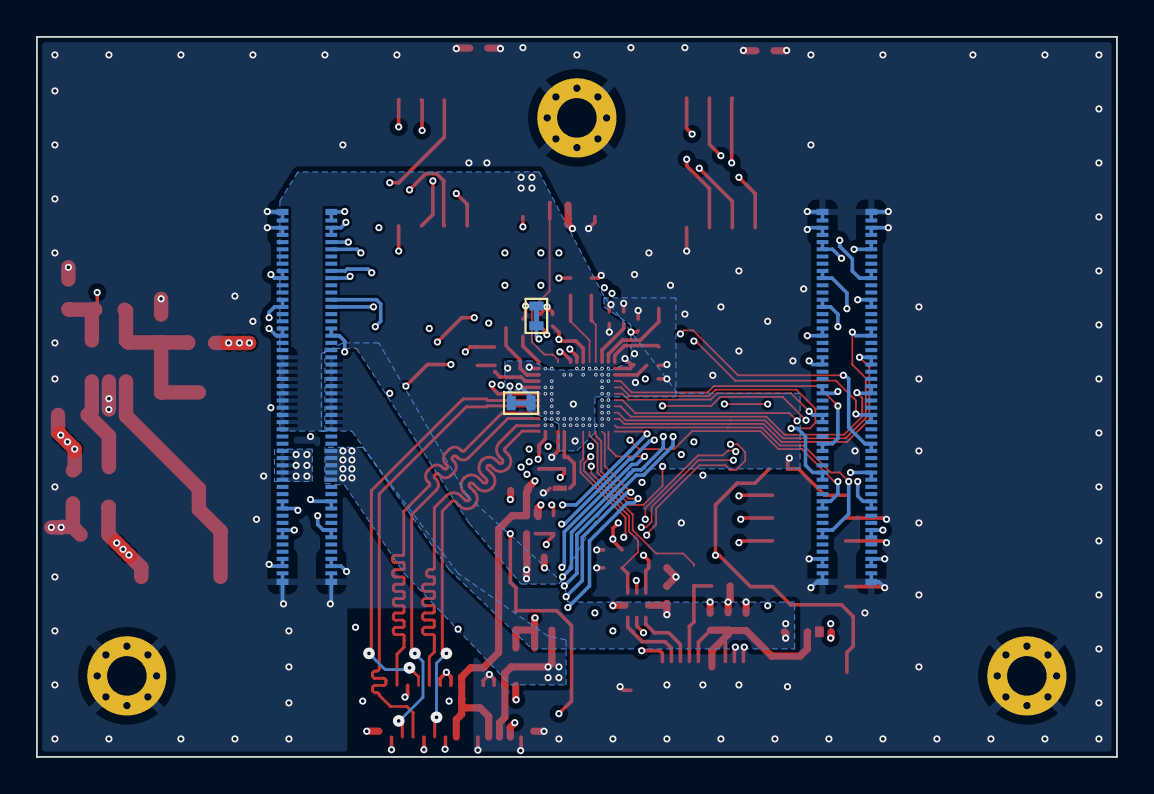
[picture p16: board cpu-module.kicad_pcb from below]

Board: 4 copper layers, 60.0 x 40.0 mm, 80 parts (4 on the bottom side), 98 nets.

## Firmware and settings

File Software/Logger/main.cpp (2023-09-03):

#include <Arduino.h>
// Quick hardware test for SPI card access.
//
#include <SPI.h>
#include "SdFat.h"
#include "driver/uart.h"
#include "sdios.h"

#define PIN_BUTT_1 25
#define PIN_BUTT_2 26
#define PIN_BUTT_3 27
#define PIN_BUTT_4 22
#define PIN_BUTT_5 13
#define PIN_BUTT_6 19
#define PIN_BUTT_7 36

#define PIN_SOLAR_SENSE 34
#define PIN_CRANK_SENSE 35
#define PIN_CRANK2_SENSE 32
#define PIN_TOTAL_SENSE 33
#define PIN_JOY_1 38
#define PIN_JOY_2 39
#define PIN_VBAT 37

#define PIN_SD_DO 14
#define PIN_SD_CD 12
#define PIN_SD_SK 21
#define PIN_SD_CS 8
#define PIN_SD_DI 7

#define PIN_LOG_UART PIN_BUTT_7//20
#define PIN_ESP_ISOLATION 4

SdFs sd;

// Serial streams
ArduinoOutStream cout(Serial);

// input buffer for line
char cinBuf[4096];
ArduinoInStream cin(Serial, cinBuf, sizeof(cinBuf));
char cinBuf1[4096];
ArduinoInStream cin1(Serial1, cinBuf1, sizeof(cinBuf1));

// SD card chip select
int chipSelect = PIN_SD_CS;

void SpinLoop(){
  cout << "Spin looping!" << endl;
  delay(2500);
  esp_restart();  
}

void ApolloSerialTask(void* arg);
void ProcessLogMessage(char* message);
void LoggingTask(void* arg);


#define CHANNEL_COUNT 25

volatile bool expStart = false;
volatile int expStartID = 0;
volatile bool expStop = false;
volatile bool eventChannels[CHANNEL_COUNT] = {0};
volatile int dataChannels[CHANNEL_COUNT] = {0};


void setup() {
  setCpuFrequencyMhz(80);
  Serial.begin(500000);

  SPI.begin(PIN_SD_SK, PIN_SD_DO, PIN_SD_DI, PIN_SD_CS); // sclk, miso, mosi, ss

  pinMode(PIN_BUTT_1, INPUT_PULLUP);
  pinMode(PIN_BUTT_2, INPUT_PULLUP);
  pinMode(PIN_BUTT_3, INPUT_PULLUP);
  pinMode(PIN_BUTT_4, INPUT_PULLUP);
  pinMode(PIN_BUTT_5, INPUT_PULLUP);
  pinMode(PIN_BUTT_6, INPUT_PULLUP);
  pinMode(PIN_BUTT_7, INPUT_PULLUP);

  pinMode(PIN_ESP_ISOLATION, OUTPUT);
  digitalWrite(PIN_ESP_ISOLATION, HIGH);

  pinMode(PIN_SOLAR_SENSE, ANALOG);
  pinMode(PIN_CRANK_SENSE, ANALOG);
  pinMode(PIN_CRANK2_SENSE, ANALOG);
  pinMode(PIN_TOTAL_SENSE, ANALOG);
  pinMode(PIN_JOY_1, ANALOG);
  pinMode(PIN_JOY_2, ANALOG);
  pinMode(PIN_VBAT, ANALOG);

  pinMode(PIN_SD_CD, INPUT_PULLUP);

  delay(1000);

  if(digitalRead(PIN_SD_CD) == HIGH){
    cout << endl<<endl<< "SD card not present." << endl << "Going to sleep..." << endl;

    esp_sleep_enable_timer_wakeup(2*1000*1000);
    esp_deep_sleep_start();
  }

  attachInterrupt(digitalPinToInterrupt(PIN_SD_CD), [](){
    ets_printf("SD card removed\n");
    delayMicroseconds(10000);
    esp_restart();   
  }, HIGH);



  if (!sd.begin(chipSelect, 4000000)) {
    if (sd.card()->errorCode()) {      
      cout << "Failed to initialize SD card!" << endl;
      SpinLoop();
    }
    cout << F("\nCard successfully initialized.\n");
    if (sd.vol()->fatType() == 0) {
      cout << F("Can't find a valid FAT16/FAT32 partition.\n");
      SpinLoop();
    }
    cout << F("Can't determine error type\n");
    SpinLoop();
  }
  cout << F("\nCard successfully initialized.\n");
  cout << endl;

  uint32_t size = sd.card()->sectorCount();
  if (size == 0) {
    cout << F("Can't determine the card size.\n");
    SpinLoop();
  }
  uint32_t sizeMB = 0.000512 * size + 0.5;
  cout << F("Card size: ") << sizeMB;
  cout << F(" MB (MB = 1,000,000 bytes)\n");
  cout << endl;
  cout << F("Volume is FAT") << int(sd.vol()->fatType());
  cout << F(", Cluster size (bytes): ") << sd.vol()->bytesPerCluster();
  cout << endl << endl;

  sd.mkdir("logs");

  FsFile fileTemp = sd.open("/test.txt", O_CREAT | O_WRITE | O_TRUNC);
  if (!fileTemp.isOpen()) {
    cout << F("Can't create file.\n");
    SpinLoop();
    return;
  }
  fileTemp.println("Everything seems to be working :)");  
  fileTemp.close();

  cout << F("Files found (date time size name):\n");
  sd.ls(LS_R | LS_DATE | LS_SIZE);

  cout << F("\n SD init success!\n");

  xTaskCreate(ApolloSerialTask, "ApolloSerialTask", 8192, NULL, 1, NULL);
  xTaskCreate(LoggingTask, "LoggingTask", 8192, NULL, 1, NULL);
}

bool firstTry = true;
void loop() {
  delay(100);
}


char serial1Buffer[4096];
char commandBuffer[4096];
int serial1BufferIndex = 0;
void ApolloSerialTask(void* arg){
  Serial.println("Starting apollo serial task");

  const uart_port_t uart_num = UART_NUM_1;
  uart_config_t uart_config = {
      .baud_rate = 19200,
      .data_bits = UART_DATA_8_BITS,
      .parity = UART_PARITY_DISABLE,
      .stop_bits = UART_STOP_BITS_1,
      .flow_ctrl = UART_HW_FLOWCTRL_CTS_RTS,
      .rx_flow_ctrl_thresh = 122,
  };
  // Configure UART parameters
  ESP_ERROR_CHECK(uart_param_config(uart_num, &uart_config));
  ESP_ERROR_CHECK(uart_set_pin(UART_NUM_1,-1, PIN_BUTT_7, -1, -1));
  // Setup UART buffered IO with event queue
  const int uart_buffer_size = (1024 * 2);
  QueueHandle_t uart_queue;
  // Install UART driver using an event queue here
  ESP_ERROR_CHECK(uart_driver_install(UART_NUM_1, uart_buffer_size, uart_buffer_size, 10, &uart_queue, 0));

  Serial1.setTimeout(10000000);
  while(true){    

      /*size_t dataReadyCount = 0;
      do{  //Sleep until there is UART data available
        esp_sleep_enable_timer_wakeup(100*1000);
        esp_light_sleep_start();
        cout << "Woke up!" << endl;
        uart_get_buffered_data_len(UART_NUM_1, (size_t*)&dataReadyCount);
        cout << "Data ready: " << dataReadyCount << endl;
      }while(dataReadyCount <= 0);*/
      
      int readNow = uart_read_bytes(UART_NUM_1,serial1Buffer+serial1BufferIndex, min(10, 4095-serial1BufferIndex), 10);      
      for(int i=0; i<readNow; i++){
        if(serial1Buffer[serial1BufferIndex] != '\n'){
          serial1BufferIndex++;
        }else{
          memcpy(commandBuffer, serial1Buffer, serial1BufferIndex);
          int commandLength = serial1BufferIndex;
          commandBuffer[serial1BufferIndex] = '\0';

          memmove(serial1Buffer, serial1Buffer+serial1BufferIndex+1, 4095-serial1BufferIndex);
          serial1BufferIndex -= serial1BufferIndex;

          cout << "Command from apollo: " << commandBuffer << endl;

          if(strncmp(commandBuffer, "TUD",3) != 0){
            cout << "Command not recognized!" << endl;
            continue;
          }

          int checksum = 0;
          for(int i=7; i<commandLength; i++){
            checksum += commandBuffer[i];
          }
          checksum = checksum % 256;
          
          if(atoi(commandBuffer+3) != checksum){
              cout << "Checksum failed!" << endl;
              continue;
          }

          ProcessLogMessage(commandBuffer+7);        
        }
      }

      if(serial1BufferIndex > 4085){
        cout << "Serial buffer overflow!" << endl;
        serial1BufferIndex = 0;
      }     
  }
 
}

void ProcessLogMessage(char* message){
  cout << "Got message of length " << strlen(message) <<  ": " << message << endl;
  char* token = strtok(message, ",");
  if(token == NULL){
    cout << "No tokens found!" << endl;
    return;
  }
  
  if(strcmp(token, "EXPSTART") == 0){
    
    token = strtok(NULL, ",");
    if(token == NULL){
      cout << "No tokens found!" << endl;
      return;
    }
    int experimentNumber = atoi(token);
    cout << "Starting experiment number: " << experimentNumber << endl;
    expStart = true;
    expStartID = experimentNumber;
    return;
  }else if(strcmp(token, "EXPEND") == 0){    
    cout << "Ending experiment" << endl;
    expStop = true;
    return;
  }else if(strcmp(token, "EVENT") == 0){    
    token = strtok(NULL, ",");
    if(token == NULL){
      cout << "No tokens found!" << endl;
      return;
    }
    int eventNumber = atoi(token);
    cout << "Got event number: " << eventNumber << endl;
    if(eventNumber >= CHANNEL_COUNT){
      cout << "Event number too high!" << endl;
      return;
    }
    eventChannels[eventNumber] = true;
  }else if(strcmp(token, "CHANNEL") == 0){
    token = strtok(NULL, ",");
    if(token == NULL){
      cout << "No tokens found!" << endl;
      return;
    }
    int channelNumber = atoi(token);

    token = strtok(NULL, ",");
    if(token == NULL){
      cout << "No tokens found!" << endl;
      return;
    }
    int channelValue = atoi(token);
    
    cout << "Got channel number: " << channelNumber << " with value: " << channelValue << endl;  
    if(channelNumber >= CHANNEL_COUNT){
      cout << "Channel number too high!" << endl;
      return;
    }
    dataChannels[channelNumber] = channelValue;
  }else{
    cout << "Unknown message type: " << token << endl;
  }
}

void DoLoggingIteration(char* file, int currentSampleNumber);

char CSVlineBuffer[1024];
void LoggingTask(void* arg){
    while(true){
      if(expStart){
        if(expStop) expStop = false;
        expStart = false;
        cout << "Starting experiment: " << expStartID << endl;

        int extraID = -1;
        char filename[32];
        do{
          extraID++;
          sprintf(filename, "/logs/%d_%d.csv", expStartID,extraID);
        }while(sd.exists(filename));        

        cout << "Creating logging file " << filename << endl;

        sd.mkdir("/logs");
        
        FsFile file = sd.open(filename, O_CREAT | O_WRITE | O_APPEND);
        if (!file.isOpen()) {
          cout << F("Can't create file.\n");
          SpinLoop();
        }

        memset(CSVlineBuffer, 0, 1024);
        int CSVlineBufferIndex = 0;
        CSVlineBufferIndex += sprintf(CSVlineBuffer+CSVlineBufferIndex, "Sample,Time,TotalPower,SolarPower,CrankPower,Joy1,Joy2,VBat,");
        CSVlineBufferIndex += sprintf(CSVlineBuffer+CSVlineBufferIndex, "B1,B2,B3,B4,B5,B6,");
        for(int i=0; i<CHANNEL_COUNT; i++){
          CSVlineBufferIndex += sprintf(CSVlineBuffer+CSVlineBufferIndex, "Event%d,", i);    
        }
        for(int i=0; i<CHANNEL_COUNT; i++){
          CSVlineBufferIndex += sprintf(CSVlineBuffer+CSVlineBufferIndex, "Channel%d,", i);    
        }

        file.println(CSVlineBuffer);
        file.flush();
        file.sync();
        file.close();

        cout << "File created" << endl;

        int iterationCount = 0;
        while(!expStop && !expStart){      
          DoLoggingIteration(filename,iterationCount);
          iterationCount++;
        }

        cout << "Stopping experiment with iterationCount of " << iterationCount << endl;
        expStop = false;


      }
    }
}

float totalPower = 0;

void DoLoggingIteration(char* fileName, int currentSampleNumber){

  FsFile file = sd.open(fileName, O_CREAT | O_WRITE | O_APPEND);
  if (!file.isOpen()) {
    cout << F("Can't create file.\n");
    SpinLoop();
    return;
  }

  memset(CSVlineBuffer, 0, 1024);
  int CSVlineBufferIndex = 0;

  long startTime = millis();
  float newTotalPower = 0;
  float crankPower = 0;
  float solarPower = 0;

  long totalCounts = 0;
  long totalCounts2 = 0;

  while(millis()-startTime<50){ //We need to do averaging because these pins might be noisy
    newTotalPower += analogRead(PIN_TOTAL_SENSE);
    if(totalCounts%10==0){
      solarPower += analogRead(PIN_SOLAR_SENSE);
      crankPower += analogRead(PIN_CRANK_SENSE);
      totalCounts2++;
    }       
    totalCounts++;
  }
  newTotalPower /= totalCounts;
  newTotalPower = newTotalPower / 4096 * 3.1 / 0.2 / 100 * 1.33;
  totalPower = newTotalPower*0.2 + totalPower * 0.8;
  solarPower /= totalCounts2;
  solarPower = solarPower / 4096 * 3.1 / 22 / 100 * 1.33;
  crankPower /= totalCounts2;
  crankPower = crankPower / 4096 * 3.1 / 0.05 / 100 * 1.33;

  float joy1 = analogRead(PIN_JOY_1);
  float joy2 = analogRead(PIN_JOY_2);
  float vBat = analogRead(PIN_VBAT) / 4096.0 * 3.1 / 0.182 * 1.33;

  CSVlineBufferIndex += sprintf(CSVlineBuffer+CSVlineBufferIndex, "%d,%u,%.5f,%.5f,%.5f,%.5f,%.5f,%.5f,",currentSampleNumber,millis(), totalPower, solarPower, crankPower, joy1, joy2, vBat);

  CSVlineBufferIndex += sprintf(CSVlineBuffer+CSVlineBufferIndex, "%d,", digitalRead(PIN_BUTT_1));    
  CSVlineBufferIndex += sprintf(CSVlineBuffer+CSVlineBufferIndex, "%d,", digitalRead(PIN_BUTT_2));    
  CSVlineBufferIndex += sprintf(CSVlineBuffer+CSVlineBufferIndex, "%d,", digitalRead(PIN_BUTT_3));    
  CSVlineBufferIndex += sprintf(CSVlineBuffer+CSVlineBufferIndex, "%d,", digitalRead(PIN_BUTT_4));    
  CSVlineBufferIndex += sprintf(CSVlineBuffer+CSVlineBufferIndex, "%d,", digitalRead(PIN_BUTT_5));    
  CSVlineBufferIndex += sprintf(CSVlineBuffer+CSVlineBufferIndex, "%d,", digitalRead(PIN_BUTT_6));  


  for(int i=0; i<CHANNEL_COUNT; i++){    
    CSVlineBufferIndex += sprintf(CSVlineBuffer+CSVlineBufferIndex, "%d,", eventChannels[i] ? 1 : 0);    
  }

  for(int i=0; i<CHANNEL_COUNT; i++){
    CSVlineBufferIndex += sprintf(CSVlineBuffer+CSVlineBufferIndex, "%d,", dataChannels[i]);    
  }
  file.println(CSVlineBuffer);
//file.println("Hou");
 //PrintSafe(file, CSVlineBuffer);
  
  if(!file.close()){
    cout << "Error closing file" << endl;
  }
  cout << "Sample written" << endl;
  cout << CSVlineBuffer << endl;
}

void PrintSafe(FsFile file, char* toPrint){
  int length = strlen(toPrint);
  cout << "Printing " << length << " characters" << endl;

  file.print(toPrint);
  file.println();
 /* for(int i=0;i<length;i++){
    size_t printed = file.print(toPrint[i]);

      if(printed != 1) cout << "Error printing char " << i << " of " << length << endl;

    if(i%1 == 0){
      //file.flush();
      if(!file.sync()){
        cout << "Error syncing file" << endl;
      }
    }  
  }*/

  file.println();
  file.flush();
  file.sync();
}

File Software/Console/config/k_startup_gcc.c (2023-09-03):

//*****************************************************************************
//
//! @file startup_gcc.c
//!
//! @brief Definitions for interrupt handlers, the vector table, and the stack.
//
//*****************************************************************************

//*****************************************************************************
//
// Copyright (c) 2022, Ambiq Micro, Inc.
// All rights reserved.
//
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
// 2. Redistributions in binary form must reproduce the above copyright
// notice, this list of conditions and the following disclaimer in the
// documentation and/or other materials provided with the distribution.
//
// 3. Neither the name of the copyright holder nor the names of its
// contributors may be used to endorse or promote products derived from this
// software without specific prior written permission.
//
// Third party software included in this distribution is subject to the
// additional license terms as defined in the /docs/licenses directory.
//
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
// This is part of revision release_sdk_4_2_0-0a31245a64 of the AmbiqSuite Development Package.
//
//*****************************************************************************

#include <stdint.h>
#include "k_config.h"

//*****************************************************************************
//
// Forward declaration of interrupt handlers.
//
//*****************************************************************************
extern void Reset_Handler(void)             __attribute ((naked));
extern void NMI_Handler(void)               __attribute ((weak));
extern void HardFault_Handler(void)         __attribute ((weak));
extern void MemManage_Handler(void)         __attribute ((weak, alias ("HardFault_Handler")));
extern void BusFault_Handler(void)          __attribute ((weak, alias ("HardFault_Handler")));
extern void UsageFault_Handler(void)        __attribute ((weak, alias ("HardFault_Handler")));
extern void SVC_Handler(void)               __attribute ((weak, alias ("am_default_isr")));
extern void DebugMon_Handler(void)          __attribute ((weak, alias ("am_default_isr")));
extern void PendSV_Handler(void)            __attribute ((weak, alias ("am_default_isr")));
extern void SysTick_Handler(void)           __attribute ((weak, alias ("am_default_isr")));

extern void am_brownout_isr(void)           __attribute ((weak, alias ("am_default_isr")));
extern void am_watchdog_isr(void)           __attribute ((weak, alias ("am_default_isr")));
extern void am_rtc_isr(void)                __attribute ((weak, alias ("am_default_isr")));
extern void am_vcomp_isr(void)              __attribute ((weak, alias ("am_default_isr")));
extern void am_ioslave_ios_isr(void)        __attribute ((weak, alias ("am_default_isr")));
extern void am_ioslave_acc_isr(void)        __attribute ((weak, alias ("am_default_isr")));
extern void am_iomaster0_isr(void)          __attribute ((weak, alias ("am_default_isr")));
extern void am_iomaster1_isr(void)          __attribute ((weak, alias ("am_default_isr")));
extern void am_iomaster2_isr(void)          __attribute ((weak, alias ("am_default_isr")));
extern void am_iomaster3_isr(void)          __attribute ((weak, alias ("am_default_isr")));
extern void am_iomaster4_isr(void)          __attribute ((weak, alias ("am_default_isr")));
extern void am_iomaster5_isr(void)          __attribute ((weak, alias ("am_default_isr")));
extern void am_iomaster6_isr(void)          __attribute ((weak, alias ("am_default_isr")));
extern void am_iomaster7_isr(void)          __attribute ((weak, alias ("am_default_isr")));
extern void am_ctimer_isr(void)             __attribute ((weak, alias ("am_default_isr")));
extern void am_uart_isr(void)               __attribute ((weak, alias ("am_default_isr")));
extern void am_uart1_isr(void)              __attribute ((weak, alias ("am_default_isr")));
extern void am_uart2_isr(void)              __attribute ((weak, alias ("am_default_isr")));
extern void am_uart3_isr(void)              __attribute ((weak, alias ("am_default_isr")));
extern void am_adc_isr(void)                __attribute ((weak, alias ("am_default_isr")));
extern void am_mspi0_isr(void)              __attribute ((weak, alias ("am_default_isr")));
extern void am_mspi1_isr(void)              __attribute ((weak, alias ("am_default_isr")));
extern void am_mspi2_isr(void)              __attribute ((weak, alias ("am_default_isr")));
extern void am_clkgen_isr(void)             __attribute ((weak, alias ("am_default_isr")));
extern void am_cryptosec_isr(void)          __attribute ((weak, alias ("am_default_isr")));
extern void am_sdio_isr(void)               __attribute ((weak, alias ("am_default_isr")));
extern void am_usb_isr(void)                __attribute ((weak, alias ("am_default_isr")));
extern void am_gpu_isr(void)                __attribute ((weak, alias ("am_default_isr")));
extern void am_disp_isr(void)               __attribute ((weak, alias ("am_default_isr")));
extern void am_dsi_isr(void)                __attribute ((weak, alias ("am_default_isr")));
extern void am_stimer_cmpr0_isr(void)       __attribute ((weak, alias ("am_default_isr")));
extern void am_stimer_cmpr1_isr(void)       __attribute ((weak, alias ("am_default_isr")));
extern void am_stimer_cmpr2_isr(void)       __attribute ((weak, alias ("am_default_isr")));
extern void am_stimer_cmpr3_isr(void)       __attribute ((weak, alias ("am_default_isr")));
extern void am_stimer_cmpr4_isr(void)       __attribute ((weak, alias ("am_default_isr")));
extern void am_stimer_cmpr5_isr(void)       __attribute ((weak, alias ("am_default_isr")));
extern void am_stimer_cmpr6_isr(void)       __attribute ((weak, alias ("am_default_isr")));
extern void am_stimer_cmpr7_isr(void)       __attribute ((weak, alias ("am_default_isr")));
extern void am_stimerof_isr(void)           __attribute ((weak, alias ("am_default_isr")));
extern void am_audadc0_isr(void)            __attribute ((weak, alias ("am_default_isr")));
extern void am_dspi2s0_isr(void)            __attribute ((weak, alias ("am_default_isr")));
extern void am_dspi2s1_isr(void)            __attribute ((weak, alias ("am_default_isr")));
extern void am_dspi2s2_isr(void)            __attribute ((weak, alias ("am_default_isr")));
extern void am_dspi2s3_isr(void)            __attribute ((weak, alias ("am_default_isr")));
extern void am_pdm0_isr(void)               __attribute ((weak, alias ("am_default_isr")));
extern void am_pdm1_isr(void)               __attribute ((weak, alias ("am_default_isr")));
extern void am_pdm2_isr(void)               __attribute ((weak, alias ("am_default_isr")));
extern void am_pdm3_isr(void)               __attribute ((weak, alias ("am_default_isr")));
extern void am_gpio0_001f_isr(void)         __attribute ((weak, alias ("am_default_isr")));
extern void am_gpio0_203f_isr(void)         __attribute ((weak, alias ("am_default_isr")));
extern void am_gpio0_405f_isr(void)         __attribute ((weak, alias ("am_default_isr")));
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

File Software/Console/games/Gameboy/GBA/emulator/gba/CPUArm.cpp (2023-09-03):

#include "GBA.h"
#include "CPU.h"
#include "Globals.h"
#include "MMU.h"
#include "../common/Settings.h"

#pragma GCC diagnostic push 
#pragma GCC diagnostic ignored "-Wunused-but-set-variable"


extern "C"{
	uint32_t am_util_stdio_printf(const char *pcFmt, ...);
}

namespace CPU
{

///////////////////////////////////////////////////////////////////////////

static int clockTicks;

static INSN_REGPARM void armUnknownInsn(u32 opcode)
{
#ifdef GBA_LOGGING
	if (settings_log_channel_enabled(LOG_UNDEFINED))
	{
		am_util_stdio_printf("Undefined ARM instruction %08x at %08x\n", opcode,
		    armNextPC-4);
	}
#endif
	CPUUndefinedException();
}

// Common macros //////////////////////////////////////////////////////////

#define CONSOLE_OUTPUT(a,b)  /* nothing */

#define NEG(i) ((i) >> 31)
#define POS(i) ((~(i)) >> 31)

// The following macros are used for optimization; any not defined for a
// particular compiler/CPU combination default to the C core versions.
//
//    ALU_INIT_C:   Used at the beginning of ALU instructions (AND/EOR/...).
//    (ALU_INIT_NC) Can consist of variable declarations, like the C core,
//                  or the start of a continued assembly block, like the
//                  x86-optimized version.  The _C version is used when the
//                  carry flag from the shift operation is needed (logical
//                  operations that set condition codes, like ANDS); the
//                  _NC version is used when the carry result is ignored.
//    VALUE_XXX: Retrieve the second operand's value for an ALU instruction.
//               The _C and _NC versions are used the same way as ALU_INIT.
//    OP_XXX: ALU operations.  XXX is the instruction name.
//    ALU_FINISH: Appended to all ALU instructions.  Usually empty, but if
//                ALU_INIT started a block ALU_FINISH can be used to end it
//                (as with the asm(...) statement in the x86 core).
//    SETCOND_NONE: Used in multiply instructions in place of SETCOND_MUL
//                  when the condition codes are not set.  Usually empty.
//    SETCOND_MUL: Used in multiply instructions to set the condition codes.
//    ROR_IMM_MSR: Used to rotate the immediate operand for MSR.
//    ROR_OFFSET: Used to rotate the `offset' parameter for LDR and STR
//                instructions.
//    RRX_OFFSET: Used to rotate (RRX) the `offset' parameter for LDR and
//                STR instructions.

// C core

#define C_SETCOND_LOGICAL \
    N_FLAG = ((s32)res < 0) ? true : false;             \
    Z_FLAG = (res == 0) ? true : false;                 \
    C_FLAG = C_OUT;
#define C_SETCOND_ADD \
    N_FLAG = ((s32)res < 0) ? true : false;             \
    Z_FLAG = (res == 0) ? true : false;                 \
    V_FLAG = ((NEG(lhs) & NEG(rhs) & POS(res)) |        \
              (POS(lhs) & POS(rhs) & NEG(res))) ? true : false;\
    C_FLAG = ((NEG(lhs) & NEG(rhs)) |                   \
              (NEG(lhs) & POS(res)) |                   \
              (NEG(rhs) & POS(res))) ? true : false;
#define C_SETCOND_SUB \
    N_FLAG = ((s32)res < 0) ? true : false;             \
    Z_FLAG = (res == 0) ? true : false;                 \
    V_FLAG = ((NEG(lhs) & POS(rhs) & POS(res)) |        \
              (POS(lhs) & NEG(rhs) & NEG(res))) ? true : false;\
    C_FLAG = ((NEG(lhs) & POS(rhs)) |                   \
              (NEG(lhs) & POS(res)) |                   \
              (POS(rhs) & POS(res))) ? true : false;

#ifndef ALU_INIT_C
#define ALU_INIT_C \
    int dest = (opcode>>12) & 15;                       \
    bool C_OUT = C_FLAG;                                \
    u32 value;
#endif
// OP Rd,Rb,Rm LSL #
#ifndef VALUE_LSL_IMM_C
#define VALUE_LSL_IMM_C \
    unsigned int shift = (opcode >> 7) & 0x1F;          \
    if (LIKELY(!shift)) {  /* LSL #0 most common? */    \
        value = reg[opcode & 0x0F].I;                   \
    } else {                                            \
        u32 v = reg[opcode & 0x0F].I;                   \
        C_OUT = (v >> (32 - shift)) & 1 ? true : false; \
        value = v << shift;                             \
    }
#endif
// OP Rd,Rb,Rm LSL Rs
#ifndef VALUE_LSL_REG_C
#define VALUE_LSL_REG_C \
    u32 shift = reg[(opcode >> 8) & 15].B.B0;                \
    u32 rm = reg[opcode & 0x0F].I;                           \
    if ((opcode & 0x0F) == 15) {                             \
        rm += 4;                                             \
    }                                                        \
    if (LIKELY(shift)) {                                     \
        if (shift == 32) {                                   \
            value = 0;                                       \
            C_OUT = (rm & 1 ? true : false);                 \
        } else if (LIKELY(shift < 32)) {                     \
            u32 v = rm;                                      \
            C_OUT = (v >> (32 - shift)) & 1 ? true : false;  \
            value = v << shift;                              \
        } else {                                             \
            value = 0;                                       \
            C_OUT = false;                                   \
        }                                                    \
    } else {                                                 \
        value = rm;                                          \
    }
#endif
// OP Rd,Rb,Rm LSR #
#ifndef VALUE_LSR_IMM_C
#define VALUE_LSR_IMM_C \
    u32 shift = (opcode >> 7) & 0x1F;                   \
    if (LIKELY(shift)) {                                \
        u32 v = reg[opcode & 0x0F].I;                   \
        C_OUT = (v >> (shift - 1)) & 1 ? true : false;  \
        value = v >> shift;                             \
    } else {                                            \
        value = 0;                                      \
        C_OUT = (reg[opcode & 0x0F].I & 0x80000000) ? true : false;\
    }
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

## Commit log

2023-09-01 preliminary studies files added
    [0_0.csv, 0_1.csv, 0_2.csv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]
2023-09-03 Preliminary study software and paths shortened
    [0_0.csv, 0_1.csv, 0_2.csv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]
2023-09-03 Enclosure and more paths shortened
    [ButtonNormal.step, ButtonPower.step, ButtonTrigger.step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]
2023-09-03 Hardware files
    [1_APO Connectors.schdoc, 1_Apollo connector.schdoc, 1_Connector.schdoc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]
2023-09-10 Port changes from the preliminary study
    [1_Main copy.schdoc, 1_Main.schdoc, 2_MCU.schdoc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]
2023-09-25 Add BOMs and more documentation
    [1_Connector.schdoc, 1_Main copy.schdoc, 1_Main.schdoc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]
2026-02-10 Rename Data/MainStudy/Data/1_0.csv to Data/MainStudy/Data/Log_Data/1_0.csv
    Added folder for log data
    [1_0.csv]
2026-02-10 Log files
    Files for participants 2-10
    [10_0.csv, 10_1.csv, 2_0.csv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]
2026-02-11 Log files
    Log files 11-20
    [11_0.csv, 11_1.csv, 12_0.csv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]
2026-02-11 Log files
    Log files 21-40
    [21_0.csv, 22_0.csv, 22_1.csv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]
2026-02-11 Log files
    Log files 27 and 41-50
    [27_0.csv, 41_0.csv, 41_1.csv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]
2026-02-11 Log files
    Log files 51-60
    [51_0.csv, 52_0.csv, 52_1.csv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]
2026-02-11 Log files
    Log file 1
    [1_0.csv]
2026-02-12 NASA-TLX user data
    [NASA-TLX.csv]
2026-02-12 Complete Survey Data
    [Complete_Survey_Data.csv]
